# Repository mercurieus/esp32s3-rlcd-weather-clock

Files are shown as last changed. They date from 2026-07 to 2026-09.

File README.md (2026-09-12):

# ESP32-S3 RLCD Weather Clock

A simple desk clock built around the [Waveshare ESP32-S3-RLCD-4.2](https://www.waveshare.com/esp32-s3-rlcd-4.2.htm) — a 4.2" reflective LCD (e-paper-like) development board.

The project was written from scratch in **VS Code with ESP-IDF**, with help from AI along the way. I really don't like working in the Arduino environment, so ESP-IDF + VS Code was the natural choice here.

Based on the original [v-cu/esp32s3-rlcd-weather-clock](https://github.com/v-cu/esp32s3-rlcd-weather-clock).

**Calendar + clock** — month grid, analogue dial, four-day forecast and a quote strip:

Simulated calendar screen

**Main clock face** — big digits with the date tucked between the colon's dots:

Simulated main screen

*Both are simulations, not photographs — generated by
`tools/render_screen_mockup.py`, which reads the layout constants straight out
of `components/ui/`. The real panel is 1-bit with no grey, so its strokes are
harder-edged and its diagonals dither; the type here is the viewer's, not the
embedded Saira and Montserrat. They are drawn from the source so they cannot
quietly fall out of date, which is what happened to the photo they replaced.*

## Features

- **A calendar screen**: Monday-first month grid with today boxed and adjacent-month days a size down, an analogue dial beside it, the four-day forecast underneath and a quote strip at the foot. Arrow buttons page through the months
- Time on a low-power reflective display, with the date tucked into the gap between the colon's two dots — the one hole the big digits leave
- Indoor temperature and humidity from the onboard SHTC3 sensor — being an onboard sensor it sits close to the electronics, so readings are approximate, not lab-grade
- Current outdoor conditions and a 4-day forecast over Wi-Fi (Open-Meteo)
- A link indicator that shows what the radio is actually doing: a tick when the last sync worked and the radio is resting, a warning when the data has gone stale, and an aerial only while a connection genuinely exists
- Battery gauge with voltage, and a charging bolt when it is on power
- RTC timekeeping (PCF85063) across resets and reboots

## Setup

Everything configurable lives in menuconfig, under **Weather Clock**:

```
idf.py menuconfig
```

| Submenu | What to set |
|---|---|
| Wi-Fi | SSID and password |
| Time | POSIX timezone string, NTP server, the two daily time-sync hours |
| Weather | Latitude and longitude, refresh interval, stale threshold |
| Battery | Low-battery warning and critical-shutdown thresholds |

Your answers are written to `sdkconfig`, which is **not tracked by git** — it
holds your Wi-Fi password and your location. `sdkconfig.defaults` is tracked and
carries only project-wide settings, so a fresh clone builds with empty
credentials and you set your own.

## Controls

| Button | Action |
|---|---|
| Left | Force an immediate weather update |
| Middle | Long press: power off · Short press: power back on |
| Right  | Not used |

## How it works

The clock spends most of its time in **light sleep** to save power, waking once a minute to refresh the time from the internal RTC. Twice a day, at **05:00** and **15:00**, it syncs the RTC against NTP. Weather runs on its own shorter cycle - **every 30 minutes** by default - and shares a Wi-Fi bring-up with the time sync whenever the two coincide. All four values are configurable.

While a USB host is attached the clock does not light-sleep at all: light sleep suspends the USB Serial/JTAG peripheral, which would make the serial port disappear. On battery it sleeps as normal.

## ⚠️ Battery life

This module is **not particularly battery-friendly**. With the screen on, it draws around **8 mA even in light sleep**, which works out to roughly **14 days** of runtime on a single charge. Keep that in mind if you're planning to run it purely on battery.

## Keeping time without a backup cell

The PCF85063 has a pin for a backup cell, and **this build has none fitted**.
That is worth knowing because it decides what the clock does when it comes back:

- After a **reset or a panic reboot**, main power never dropped, so the RTC kept
  running and the time is still good.
- After an **unplug**, the oscillator stopped. The chip then returns a perfectly
  well-formed *wrong* time, and the only thing that says so is bit 7 of the
  seconds register — the oscillator-stop flag.

So the firmware reads that flag rather than trusting the value. With no network
and no valid RTC time it shows `--:--` until a sync lands, instead of a
confident and wrong `00:00`. A missed sync is never fatal either: it keeps
running on whatever time it has and retries on the next weather slot.

Fit a backup cell and time survives an unplug too.

## The finished build

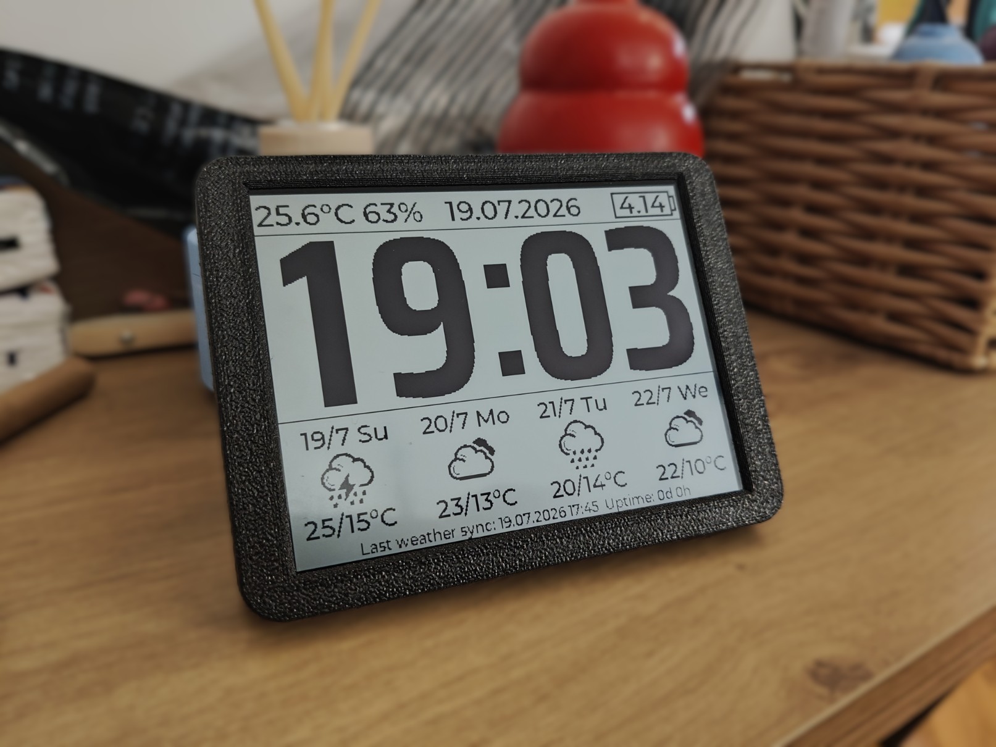
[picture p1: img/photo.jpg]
Finished clock


*The 3D-printed case. Note that this photo predates the current UI — the top bar
has since been rebuilt and the date moved onto the face.*

## Checking a layout without flashing

A 400px-wide 1-bit panel has no room to be wrong, and the way to get it wrong is
to try a layout with a flattering sample. `Fri 21` fitted the date column; `Wed
24` did not, and only one of those was ever typed in by hand.

```
python tools/verify_calendar_layout.py     # exits non-zero on an overflow
python tools/render_screen_mockup.py       # regenerate the mockup above
```

The checker measures against the **real** LVGL font tables — it parses the
`adv_w` values out of the generated font C files, including the sparse ranges
where `°` and the `LV_SYMBOL_*` glyphs live — and then tests the widest value
each field can hold rather than a typical one. Run it after touching anything in
`components/ui/`.

`TODO.md` carries the open leads, including a measurement that is suggestive but
not yet conclusive. `CHANGELOG.md` records what has changed and what is still
unverified.

## Hardware

- [Waveshare ESP32-S3-RLCD-4.2](https://www.waveshare.com/esp32-s3-rlcd-4.2.htm)

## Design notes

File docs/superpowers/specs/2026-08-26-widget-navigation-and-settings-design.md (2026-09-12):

# Widget navigation, Vista-style Cal+Clock, and on-device settings

Date: 2026-08-26
Status: approved for planning

## Context

The firmware currently has two screens (Main, Cal+Clock) toggled by a single
button, and no way to change anything without reflashing. This design adds
two-button navigation with focus and detail views, an on-device settings menu
backed by NVS, and redraws the Cal+Clock screen after the Windows Vista/7
taskbar clock flyout.

## Goals

- Two-button navigation: cycle screens, focus elements within a screen, open
  a detail view for the focused element.
- On-device settings for display preferences, timezone, sync schedule, plus
  read-only device info and a few actions.
- Cal+Clock redrawn as the Vista/7 flyout, with the second hand restored.
- Button hints as a transient overlay, not permanent screen furniture.

## Non-goals

- Wi-Fi AP + web configuration portal. Deferred; Wi-Fi credentials stay
  compile-time in `clock_config.h`.
- Text entry of any kind. Two buttons cannot do it usefully.
- Partial-panel refresh. `RLCD_Display()` hardcodes a full-screen window;
  changing that is a separate driver change, tracked as a follow-up.

## Hardware constraints

These shape every decision below and are easy to forget.

- **400 x 300, 1 bit.** `Lvgl_FlushCallback` in `main/main.cpp` thresholds
  RGB565 at `0x7fff`. There is no grey. Any stroke thinner than 2 px is
  anti-aliased into the threshold and breaks up.
- **Full-screen render on every refresh.** `LV_DISPLAY_RENDER_MODE_FULL` plus
  a 120000-iteration threshold loop plus a 15 KB SPI write plus a 50 ms
  `vTaskDelay`. Refresh only when something changed.
- **LVGL built-in allocator, 64 KB pool** (`CONFIG_LV_MEM_SIZE_KILOBYTES=64`).
  Object count matters. The Info page exposes free LVGL heap so this stays
  visible.
- **Light sleep between ticks.** The task wakes once a second or on a GPIO
  edge. Anything time-based must be driven from that tick; LVGL timers do not
  run on their own because `lv_timer_handler()` is only called from
  `Lvgl_Refresh()`.
- **Two usable GPIO buttons.** Select = `GPIO_NUM_18`, OK = `GPIO_NUM_0`.
  Confirmed, not assumed: the esp32s3-rlcd-smart-clock project on this same
  board does `ButtonInput s_buttons(GPIO_NUM_18, GPIO_NUM_0)`. The third case
  cutout is the PMU power button and is not software-readable.
- **ES8311 output codec on the shared I2C bus**, I2S on MCLK `GPIO_NUM_16`,
  BCLK `GPIO_NUM_9`, WS `GPIO_NUM_45`, DOUT `GPIO_NUM_8`, speaker PA enable
  `GPIO_NUM_46`. The speaker itself plugs into a header and may not be fitted.

## Architecture

New components, each with one job:

| Unit | Responsibility | Depends on |
|---|---|---|
| `components/input/buttons.[ch]` | Debounce, classify short/long press, expose events | driver/gpio, esp_sleep |
| `components/ui/nav.[ch]` | Navigation state machine. Pure C, no LVGL, no ESP-IDF | nothing |
| `components/ui/overlay.[ch]` | Top bar + hint overlay + focus frame on `lv_layer_top()` | lvgl |
| `components/settings/settings.[ch]` | Typed settings struct, NVS load/save, TZ table | nvs_flash |
| `components/ui/screen_settings.[ch]` | Settings list rendering and row actions | lvgl, settings |

`nav.c` having no dependencies is deliberate: it is the piece most likely to
harbour bugs and the only piece that can be tested away from hardware.

## Input layer

`user_config.h` gains:

```c
#define BTN_OK_PIN      GPIO_NUM_0    /* BOOT, confirmed working */
#define BTN_SELECT_PIN  GPIO_NUM_18   /* KEY - confirmed against sibling board */
```

Both configured input, pull-up, active low, with
`gpio_wakeup_enable(pin, GPIO_INTR_LOW_LEVEL)`.

On wake with cause `ESP_SLEEP_WAKEUP_GPIO`, poll both pins; whichever reads
low is the pressed one. Debounce 20 ms, then poll at 20 ms until release or
`BTN_LONG_MS` (600). A press held past 600 ms emits its LONG event
immediately, then waits for release without emitting again.

Emits exactly one of: `BTN_EV_SELECT_SHORT`, `BTN_EV_SELECT_LONG`,
`BTN_EV_OK_SHORT`, `BTN_EV_OK_LONG`.

This replaces the inline busy-wait currently in `clock_task`.

## Navigation state machine

```c
typedef enum { NAV_SCREEN, NAV_FOCUS, NAV_DETAIL, NAV_SETTINGS } nav_mode_t;
```

| Mode | Select short | Select long | OK short | OK long |
|---|---|---|---|---|
| `SCREEN` | next screen | — | enter `FOCUS` (index 0) | `SETTINGS` |
| `FOCUS` | next element (wraps) | back to `SCREEN` | open `DETAIL` | `SETTINGS` |
| `DETAIL` | — | back to `FOCUS` | back to `FOCUS` | `SETTINGS` |
| `SETTINGS` | next row (wraps) | exit to `SCREEN` | cycle value / run action | — |

Screen cycle: **Main -> Cal+Clock -> Main**. Settings is modal and not in the
cycle. Detail is a transient overlay, not a screen.

Focusable elements:

- **Main**: `[indoor sensor] [day1] [day2] [day3] [day4]` — 5 elements.
- **Cal+Clock**: the days of the displayed month, 1..N. Advancing past N
  browses to the next month at day 1; retreating before 1 browses to the
  previous month at its last day. This is what makes the `< >` month arrows
  meaningful.

`nav_handle(nav_state_t *, btn_event_t)` returns a `nav_action_t` describing
what the caller must redraw. The state machine itself touches no widgets.

## Shared overlay on `lv_layer_top()`

`lv_layer_top()` floats above whichever screen is loaded and survives
`lv_screen_load()`. Moving the top bar there **removes the duplication added
in ccffbf5**: `calendar_update_top_bar()` and the calendar's second widget set
are deleted, and one set of temp/humidity/date/battery widgets serves every
screen.

The focus frame also lives here, positioned in absolute screen coordinates, so
one frame object can outline an element on any screen — including the top bar
itself, which is how Main's `[indoor sensor]` element gets highlighted.

Screens shrink to y 38..300. Main barely moves: it already had a rule at y=34,
so deleting its own top-bar widgets leaves the rest in place.

### Hint overlay

A hidden box on `lv_layer_top()`, roughly 320x40 centred near the bottom,
showing the current mode's button labels:

```
   Select: next day        OK: details        hold OK: menu
```

Shown for 5 s at boot and 2.5 s after any button event. **Auto-hide is driven
from the one-second task tick, not an LVGL timer** — `lv_timer_handler()` only
runs inside `Lvgl_Refresh()`, so a timer would never fire while idle. The task
holds `hint_until_ms` and hides the overlay on the first tick past it.

Cost: one extra refresh roughly 2.5 s after each button press.

## Cal+Clock screen

```
+--------------------------------------------------+  y
|  25.6C 63%   19.07.2026              [4.14]      |  0..36   shared top bar
|==================================================|  34..36  rule
|            Wednesday, 26 August 2026             |  38..56  montserrat_16
|   <  August 2026  >            .-''''''-.        |  58..74  montserrat_14
|   Mo Tu We Th Fr Sa Su       .'    |     '.      |
|   28 29 30 31  1  2  3      /      |       \     |  76..216 grid, 7 x 20
|    4  5  6  7  8  9 10     |       o----    |    |  62..212 dial, 150 sq
|   11 12 13 14 15 16 17     |      /         |    |
|   18 19 20 21 22 23 24      \    /         /     |
|   25[26]27 28 29 30 31       '.          .'      |
|    1  2  3  4  5  6  7         '-......-'        |
|                                  19:03:42        |  214..232 montserrat_16
|--------------------------------------------------|  236     rule
| (~)Su  (/)Mo  (~)Tu  (~)We                       |  240..276 weather row
| 25/15  23/13  20/14  22/10                       |
|--------------------------------------------------|
| Sunrise 05:52  Sunset 20:31  Day 14h39m  Moon 68%|  280..295 montserrat_12
+--------------------------------------------------+
```

Geometry constants (all derived, none eyeballed):

- Grid columns keep the current scheme: 7 fixed-width centred labels, header
  as line 0, `CAL_COL_X0 = 6`, `CAL_COL_W = 30`, `CAL_ROW_H = 20`, pitch from
  `text_line_space`, not `pad_row`.
- Dial `x 238..388`, `y 62..212`.
- Today box and focus frame both derive from the column constants, so they
  cannot drift off a cell.

### Leading and trailing days

Vista greys them. There is no grey on this panel. They render in
**montserrat_12 against the month's montserrat_14**, which reads as
subordinate without needing a second colour.

### Dial

- 12 major ticks, 3 px wide, 10 px long.
- 48 minor ticks, 2 px wide, 4 px long. At r=68 adjacent ticks are ~7 px
  apart, so 2 px survives the threshold. 1 px does not — that is what made the
  old minor ticks noise.
- Hour hand 5 px / 34 long, minute 3 px / 52, **second 2 px / 58**, all pure
  black. The old `0x888888` second hand thresholded to white, which is why it
  was invisible.
- 9x9 square hub.

### Day detail overlay

OK on a focused day opens: weekday, ISO week number, day of year, days from
today, and — if the day falls inside the 4-day forecast — its icon, high/low,
rain probability and wind.

### Sun and moon

Sunrise, sunset and day length come from Open-Meteo. Moon phase is computed
locally, no network:

```
phase = frac((jd - 2451550.1) / 29.530588853)     /* ref new moon 2000-01-06 */
illum = (1 - cos(2*pi*phase)) / 2
```

Named across eight buckets (new, waxing crescent, first quarter, waxing
gibbous, full, waning gibbous, last quarter, waning crescent).

## Weather API extension

The existing single request gains three daily fields at no extra network cost:

```
&daily=weathercode,temperature_2m_max,temperature_2m_min,
       sunrise,sunset,precipitation_probability_max,wind_speed_10m_max
```

`WeatherDay` gains `sunrise_min`, `sunset_min` (minutes past local midnight),
`precip_prob`, `wind_max`. `timezone=auto` is already set, so the returned sun
times are local.

## Settings

One scrolling list on its own screen. Select moves the row, OK cycles the
value or runs the action, long Select exits.

**Display** — time 24h/12h · date format Weekday (`Fri 26 Aug`, default) /
`DD.MM.YYYY` / `YYYY-MM-DD` / `MM/DD/YYYY` · °C/°F · show seconds on/off ·
week starts Monday/Sunday

The Weekday format is `EEE D MMM` in CLDR terms — abbreviated weekday, day,
abbreviated month, no year — the pattern calendar apps use for a day header.
It ships as the default because it is what the shared overlay's top bar
actually shows (see the Cal+Clock mockup); the year is not lost, since the
opened calendar's own heading carries it. `WEEKDAY_NAMES` already exists in
`clock_task.c` for the forecast row; the top bar needs its 3-letter form,
plus a 3-letter month table that does not yet exist anywhere in the
firmware.

**Time** — timezone from a preset POSIX-TZ table · sync hour 1 (0..23) ·
sync hour 2 (0..23)

**Actions** — sync weather now · sync time now · reboot

**Info** (read-only) — firmware version · uptime · battery mV and % · free
LVGL heap, internal heap, PSRAM · SSID and RSSI · last NTP sync · RTC state

### NVS schema

```c
#define SETTINGS_VERSION 1

typedef struct {
    uint8_t version;
    uint8_t time_24h;         /* 0/1                                    */
    uint8_t date_fmt;         /* 0 Weekday, 1 DD.MM.YYYY, 2 YYYY-MM-DD, 3 MM/DD/YY */
    uint8_t temp_f;           /* 0/1                                    */
    uint8_t show_seconds;     /* 0/1                                    */
    uint8_t week_start_sun;   /* 0/1                                    */
    uint8_t tz_index;         /* index into TZ_TABLE                    */
    uint8_t sync_hour_1;      /* 0..23                                  */
    uint8_t sync_hour_2;      /* 0..23                                  */
    uint8_t reserved[7];      /* room to grow without a version bump    */
} settings_t;
```

Namespace `clock`, key `settings`, stored as a blob. Missing or mismatched
version loads defaults and writes them back. Defaults: 24h, **Weekday date
format**, °C, seconds on, Monday, EET, 05:00 / 15:00. This is the one default
that changes device behaviour rather than preserving it — a deliberate choice,
since the redesigned overlay is built around the shorter format and reverting
to `DD.MM.YYYY` is one Settings press away.

The TZ table holds roughly sixteen labelled POSIX strings (UTC, London,
Berlin, Kyiv, Moscow, Dubai, India, Bangkok, China, Japan, Sydney, New York,
Chicago, Denver, Los Angeles). Default is the current
`EET-2EEST,M3.5.0/3,M10.5.0/4`.

## Chimes

An old-clock chime, synthesised rather than sampled. Nothing is stored in
flash: a struck bell is a handful of inharmonic partials with exponential
decay, which is roughly twenty lines of arithmetic.

### Timbre

Each strike sums five partials at the classic bell ratios against the
strike note, with higher partials decaying faster:

| Partial | Ratio | Relative gain | Decay |
|---|---|---|---|
| hum | 0.5 | 0.30 | slowest |
| fundamental (prime) | 1.0 | 1.00 | slow |
| tierce | 1.2 | 0.50 | medium |
| quint | 1.5 | 0.25 | fast |
| nominal | 2.0 | 0.60 | fast |

Output at 16 kHz mono, matching the sibling project's codec configuration.
That is ample: the highest partial of the highest bell is under 900 Hz.

### What plays

Westminster quarters, in E major, on the four bells
E4 329.63, F#4 369.99, G#4 415.30, B3 246.94:

| Time | Phrase |
|---|---|
| :15 | G# F# E B |
| :30 | E G# F# B, B F# G# E |
| :45 | E G# F# B, B F# G# E, G# E F# B |
| :00 | G# F# E B, B E F# G#, B F# G# E, G# E F# B, then the hour strike |

**The hour strike is what makes each hour sound different**: a deeper bell
(E3, 164.81 Hz) struck once at one o'clock through twelve times at twelve,
roughly two seconds apart. This is what a grandfather clock does, and it is
the classic way an hour is audibly identifiable without looking.

Twelve o'clock therefore runs about 45 seconds. Playback lives on its own
low-priority `chime_task` fed by a queue, so the one-second display tick and
the second hand keep running throughout. Audio is generated in chunks and
streamed to `esp_codec_dev_write`; a full phrase is never buffered whole.

The PA on `GPIO_NUM_46` is enabled only for the duration of a phrase.

### Settings rows

- **Chimes** — Off / Hour strike only / Westminster + strike. Default **Off**,
  because a speaker may not be fitted and an unexpected 45-second chime is a
  poor first-boot experience.
- **Quarter chimes** — Off / On. Only meaningful with Westminster selected.
- **Quiet hours** — Off / 22:00-08:00 / 23:00-07:00 / custom start and end.
  Default 22:00-08:00. Nothing chimes inside the window.
- **Volume** — 0 to 100 in steps of 10, applied through the codec.
- **Test chime** — an action row that plays a single strike, so the speaker
  can be verified without waiting for an hour boundary.

`settings_t` gains `chime_mode`, `chime_quarters`, `quiet_start`, `quiet_end`
and `volume`, taken from the existing `reserved[7]` bytes, so the NVS version
byte does not need to change.

### Scheduling

The existing one-second tick already knows the minute boundary. The chime
scheduler fires when the minute changes to 00, 15, 30 or 45, is enabled for
that quarter, and falls outside quiet hours. It queues a request and returns
immediately.

A missed boundary is never made up: if the device was asleep, resyncing or
mid-chime, the request is dropped rather than played late.

## RTC stores UTC

`wifi_sync.c:60-61` sets `TZ` then calls `localtime_r`, so `Pcf85063_SetTime()`
writes **local** time to the RTC.

Two consequences: a runtime timezone setting would not take effect until the
next NTP sync, up to 12 hours later; and — independent of this work — **at a
DST boundary the clock stays an hour wrong until 05:00 or 15:00.**

Change: the RTC stores UTC. `Pcf85063_GetTime()` yields UTC, which is
converted to a `time_t` and passed through `localtime_r()` for display, with
`TZ` set from `settings.tz_index` at boot and whenever the setting changes.

Migration: devices flashed with this build have a local-time RTC until their
first NTP sync, after which they are correct. Worst case is one wrong-by-offset
period on first boot after update; acceptable and self-healing.

This lands as its own commit, before any navigation work, so timekeeping can
be verified in isolation.

## Refresh and power

| State | Refresh rate |
|---|---|
| Main active | 1/s (colon blink, unchanged) |
| Cal+Clock active | 1/s (second hand) |
| Settings active | on input only |
| Detail overlay | on input only |
| Any state | one extra refresh when a hint expires |

The second hand costs exactly what Main's colon blink already costs, so it is
not a regression — but it only ticks while Cal+Clock is the active screen.

## Testing

No host C compiler is available on this machine (only the Espressif
cross-toolchain), so:

- **Nav state machine** — `nav.c` stays dependency-free so it can be host
  tested later. For now, the transition table is mirrored in a Python model
  and checked exhaustively over every (mode, event, screen, focus index)
  combination against invariants: mode always valid, focus index always in
  range, every mode reachable, every mode can return to `SCREEN`, Settings
  always reachable and always exitable.
- **Layout geometry** — asserted against real font metrics parsed from the
  LVGL font tables, not eyeballed. This is the method that caught the column
  alignment and quote-wrapping problems in ccffbf5.
- **Calendar month browsing** — extends the existing 12-year harness to cover
  crossing month and year boundaries in both directions.
- **Moon phase** — checked against known new and full moon dates.
- **Settings persistence** — round-tripped on device via the Info page across
  a reboot.

## Milestones

Each builds, flashes, and is verifiable on its own.

1. RTC to UTC, timezone applied for display only.
2. Input layer + nav state machine + hint overlay. Select cycles Main and
   Cal+Clock; long OK opens a stub Settings screen. Also logs GPIO transitions
   so the Select pin can be confirmed.
3. Overlay onto `lv_layer_top()`; delete the duplicated top bars.
4. Cal+Clock Vista redraw: dial with second hand, month browsing, day detail.
5. Weather API extension and the sun/moon strip.
6. Settings screen and NVS.
7. Chimes: codec bring-up, bell synthesis, schedule, chime settings rows.

## Risks

- **A speaker may not be fitted.** The board only provides a header. Chimes
  default to off, the ES8311 is probed over I2C at boot, and if it does not
  answer the chime rows render as "no audio hardware" rather than failing.
- **Chime playback is long.** Westminster on the hour plus twelve strikes runs
  around 45 s. It must not block the display tick, hence the dedicated task.
- **LVGL 64 KB heap.** Settings rows, the hint overlay and the detail view all
  add objects. The Info page reports free LVGL heap so pressure is visible;
  if it becomes tight, the Settings list is the natural candidate for building
  rows on demand rather than up front.
- **`lv_layer_top()` persistence across `lv_screen_load()`** is assumed and
  must be confirmed early in milestone 3, since the whole overlay design rests
  on it.
- **Hint overlay refresh cost** adds one full-panel write per button press.
  Measurable, but worth watching on battery.

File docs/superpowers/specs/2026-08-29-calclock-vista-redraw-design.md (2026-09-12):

# Cal+Clock Vista redraw and accurate SPI transfer wait

Date: 2026-08-29
Status: approved for planning

## Context

This is milestone 4 of
`docs/superpowers/specs/2026-08-26-widget-navigation-and-settings-design.md`,
written out and refined into its own spec the same way milestones 1-3 became
`docs/superpowers/plans/2026-08-26-navigation-foundation.md`. It formalizes
the visual decisions made in a mockup session and captured in
`TEMP-visual-design-notes.md` (delete that file once this spec is committed —
its content is folded in below, with one section explicitly superseded, see
"Nav model" below), resolves the one question that session left open, and
adds a small, unrelated fix to the SPI transfer path found worth doing at the
same time since milestone 4 is what makes it matter (a live second hand,
ticking every second, is the first thing on this device that benefits from
not padding every refresh with a guessed delay).

Two things surfaced during brainstorming are explicitly **out of scope** here
and noted for their own future spec:

- **Windowed/partial SPI refresh.** Still deferred, as in the parent spec's
  non-goals. The transfer-wait fix below is an orthogonal, lower-risk
  improvement chosen instead — it does not reduce bytes transferred, only
  removes a padded guess, and touches none of the panel's undocumented
  column/row addressing.
- **A "weather station" screen** (live current conditions, hourly forecast,
  an analog clock, styled after a classic weather station instrument). A real
  idea, but it is a new top-level screen with its own API surface
  (`hourly=...`, `current_weather=true` — both beyond what milestone 5
  already plans) and its own visual language. Noted on the roadmap; not
  designed here.

## Goals

- Redraw the existing Cal+Clock screen after the Windows Vista/7 taskbar
  clock flyout: plain analog dial with a working second hand, month
  calendar grid, metal-styled header/bezel/buttons via dithering.
- Working month browsing via the `<`/`>` arrows, replacing the parent
  spec's per-day focus (see "Month browsing" below for why).
- Replace the SPI flush path's blind `vTaskDelay(50)` with an accurate wait
  on the transfer's actual completion.

## Non-goals

- Anything in the "out of scope" list above.
- Any change to `nav.c` (see "Nav model" below).
- Double-buffering `DispBuffer` for a truly non-blocking transfer. Considered
  during brainstorming and rejected for now as more complexity than this
  milestone's payoff justifies — see "SPI transfer wait" below. Left as a
  future option if the accurate-wait version ever proves insufficient.

## Nav model (resolved)

Main and Cal+Clock remain two equal, symmetric top-level screens, cycled by a
short Select press, exactly as implemented in the navigation-foundation plan.
**No `nav.c` change.**

This explicitly supersedes `TEMP-visual-design-notes.md`'s "Calendar
drill-down, not buttons-on-a-tile" section in full: the idea of Main gaining
a sixth focus tile that opens Cal+Clock as a Detail overlay is rejected.
There is no overview/opened distinction — Cal+Clock is drawn the same way
however you arrive at it. The round `< >` month buttons described there as
living "only in the opened view" simply don't apply to that framing; see
"Dial and grid" below for where month browsing actually lives.

## SPI transfer wait

**Current state.** `Lvgl_FlushCallback` (`main/main.cpp:17`) writes the
dirty pixels into `DispBuffer` via `RLCD_SetPixel`, calls
`RlcdPort.RLCD_Display()`, which sends the whole buffer through
`esp_lcd_panel_io_tx_color()` — itself asynchronous, queuing onto SPI/DMA and
returning quickly — then immediately calls `lv_disp_flush_ready()`.
`Lvgl_Refresh()` (`components/app_bsp/lvgl_bsp.cpp:37`) then unconditionally
sleeps 50 ms before returning to the caller, on every single refresh. That
delay is not just a wasted guess: `DispBuffer` is a single, persistent
full-frame buffer (`components/port_bsp/display_bsp.cpp`), not
double-buffered, so the delay is what currently prevents the next refresh's
`RLCD_SetPixel` calls from mutating a buffer whose previous contents are
still being DMA'd out — a real, if accidental, safety mechanism.

**Change.** Register `on_color_trans_done` via
`esp_lcd_panel_io_register_event_callbacks()` (not a field on the SPI IO
config — it's registered separately, see `esp_lcd_types.h`), backed by a
binary FreeRTOS semaphore signalled from that callback.

**Where the wait actually has to go is the subtle part.** Waiting at the top
of `RLCD_Display()` — the first design considered here — is too late: by the
time `RLCD_Display()` is called, `Lvgl_FlushCallback` has *already* written
this frame's pixels into `DispBuffer` via `RLCD_SetPixel`, so a still-in-
flight previous transfer could already have raced against those writes
before anyone waited for anything. The wait must happen **before the pixel
writes**, not before the send. Concretely:

- `DisplayPort` gains a `SemaphoreHandle_t xfer_done_` member: a **binary**
  semaphore (only "is a transfer outstanding" matters, never a count),
  created in the constructor and given once immediately so the first call
  doesn't block forever waiting for a transfer that never started.
- A new public method, `void RLCD_WaitTransferDone()`, blocks on it.
- The registered callback gives the semaphore from ISR context
  (`xSemaphoreGiveFromISR`).
- `Lvgl_FlushCallback` (`main/main.cpp:17`) calls `RlcdPort.RLCD_WaitTransferDone()`
  as its **first statement**, before its `RLCD_SetPixel` loop — this is what
  actually closes the race, for both the ordinary case and `PARTIAL` render
  mode's multiple flush calls per refresh (each flush's writes wait for
  whatever the *previous* flush's `RLCD_Display()` kicked off, whether that
  was in this refresh cycle or the last one).
- `RLCD_Display()` itself is otherwise unchanged — it sends immediately,
  trusting the caller already waited before writing.
- `Lvgl_Refresh()` drops its `vTaskDelay(50)` entirely.

This still blocks the caller — `DispBuffer` being single-buffered means it
must — but for the transfer's actual duration (≈24 ms at the current 10 MHz
SPI clock for the full 30000-byte buffer) rather than a padded 50 ms guess,
and it is now a guarantee instead of a hope. True non-blocking would need
double-buffering `DispBuffer` and tracking render-pass boundaries across
possibly multiple `PARTIAL`-mode flush calls per refresh — rejected above as
more complexity than this milestone's payoff justifies.

**Cross-checked against the sibling `esp32s3-rlcd-smart-clock` project**,
which shares this exact driver (`DisplayPort`, same `RLCD_Display()`, same
`esp_lcd_panel_io_tx_color`, same 10 MHz `pclk_hz`) with no LVGL involved —
its own animation loop (`main/display_animations.cpp:74`) calls
`RLCD_Display()` and waits only 5 ms, not 50, for the same 30000-byte
buffer. Neither project has a completion callback; that 5 ms is as much a
guess as our 50 ms, just a tighter one, and is exposed to the same
single-buffer race in principle even if it hasn't produced visible
artifacts there in practice. It's useful evidence that the true transfer
time is well under 50 ms, but it is not a pattern worth copying — it
confirms the direction (replace the guess with a real wait), not a number
to borrow.

**Testing.** Build and flash; confirm on hardware that the Main and
Cal+Clock screens still render correctly and nothing regresses (this is a
timing-only change, so "looks identical, feels identical or snappier" is the
bar — no new automated test is meaningful here).

## Dial and grid

**Dial:** plain Vista style — ticks only, no numerals, no chapter ring, no
outlined hand polygons (the engraved/skeuomorphic treatment explored earlier
was rejected and must not be resurrected). Geometry:

| Element | Spec |
|---|---|
| Dial position | x 238..388, y 62..212 |
| Major ticks | 12, 3 px wide, 10 px long |
| Minor ticks | 60 (not 12 — see below), 2 px wide, 4 px long |
| Hour hand | 5 px wide, 34 px long |
| Minute hand | 3 px wide, 52 px long |
| Second hand | 2 px wide, 58 px long |
| Hub | 9x9 px square |
| Colour | all pure black — no `0x888888` on this panel; that grey is what made the parent spec's original second hand thresholded invisible |

Minor ticks are 60, not the 12 the parent spec originally specified: at
r=58 adjacent 60-tick spacing is ~6.3 px, wide enough for a 2 px tick to
survive the 1-bit threshold; a 1 px tick does not, which is what produced
speckle noise when this was first tried.

**Grid:** unchanged from the parent spec — 7 fixed-width centred columns,
header as line 0, `CAL_COL_X0 = 6`, `CAL_COL_W = 30`, `CAL_ROW_H = 20`, pitch
from `text_line_space` (not `pad_row`). Leading/trailing days render in
montserrat_12 against the current month's montserrat_14, reading as
subordinate without needing a second colour this panel doesn't have.

**Month browsing:** as the parent spec already specifies — advancing focus
past the last day of the displayed month browses into the next month at day
1 (and symmetrically backward). The `< >` glyphs next to the month/year
header are a static visual affordance for this, not separate focusable
elements — no additional nav.c or focus-count change.

## Metal via dithering

Two techniques, both native to 1-bit displays, applied to structure only —
**never the dial face**, which stays the plain style specified in "Dial and
grid" above:

- **Ordered dithering** (Bayer 4x4 matrix): a real per-pixel grey gradient,
  thresholded through the matrix *before* LVGL sees it — a plain grey fill
  collapses to solid under the panel's hard threshold, so the gradient must
  already be dithered pixels by the time it's drawn.
- **Bevel pairs** for relief: a light edge on one side, dark on the other,
  two 1 px lines per edge.
- **Hard rule:** never dither behind text — it destroys glyphs at this
  panel's pitch. Anything carrying type sits on plain white.

Applied to: the header rail (dithered band, dark lower lip, bright ridge
about a third of the way down, dark lower lip again — a "rolled rail" rather
than a flat bar), the dial's bezel, and the month `< >` buttons (shaded via
hemisphere-normal-against-light-vector, not a flat gradient fill). The
shared top bar's four readings (temp, humidity, date, battery) sink into the
rail as recessed white plaques — dark edge top-left, light edge
bottom-right — which is what keeps their text off the dither per the hard
rule above.

**The header rail is `components/ui/overlay.c`'s shared top bar** — on
`lv_layer_top()`, so this reaches Main too, not just Cal+Clock. Confirmed
with the user: one visual language for both screens, not a Cal+Clock-only
treatment. The dial bezel and month buttons remain Cal+Clock-only, in
`screens.c`.

**Hardware verification required before committing to this.** The mockup's
dither assumes the panel renders isolated single pixels cleanly; if adjacent
dithered pixels bleed together the checker pattern collapses to flat grey
and the whole technique needs rethinking. This is the first implementation
step (see "Implementation notes" below) — flash a standalone test pattern
(the tone-ramp swatches from the mockup) and confirm on the actual screen
before writing any of the bezel/rail code for real.

Exact pixel geometry for the metal treatment (dither matrix tiling, bevel
positions, rail band y-ranges) was worked out live in the mockup as
JavaScript, not yet transcribed into tables here — the implementation plan
must derive and record these the same way the rest of this document does,
not eyeball them from the mockup.

## Month browsing (revises the parent spec)

The parent spec gave Cal+Clock per-day focus (1..N days) with wrap-forward
into the next month and wrap-backward into the previous, plus a day-detail
overlay (weekday, ISO week, day of year, days from today, weather). Dropped
during brainstorming: per-day focus isn't needed, only month browsing is —
and `nav.c` has no backward-navigation event at all (`SELECT_SHORT` only
ever moves focus forward, wrapping), so per-day "retreat before day 1" was
never actually reachable through the two-button vocabulary as originally
worded. **This whole day-focus and day-detail design is replaced** by:

Cal+Clock gains exactly two focusables: the `<` and `>` month arrows
(`nav_focus_count(NAV_SCREEN_CALCLOCK) = 2`, index 0 = previous, index 1 =
next — up from 0 today). Select cycles focus between them, exactly as
`nav.c` already does for Main's five. OK on a focused arrow shifts the
*displayed* month in that direction and redraws the grid.

`nav.c` still has no notion of "perform an action, don't open a view" — OK
on a focused element unconditionally enters `NAV_DETAIL`. Cal+Clock uses the
same escape hatch `NAV_SETTINGS` already relies on ("caller acts on the row,
then redraws"): `clock_task.c` recognizes `mode == NAV_DETAIL && screen ==
NAV_SCREEN_CALCLOCK`, performs the month shift, and immediately sets
`s_nav.mode` back to `NAV_FOCUS` in the same handler — the user never sees a
detail view, an OK press on `<`/`>` just feels like it directly changes the
month, and repeated presses browse further. No `nav.c` change.

**Displayed vs. real "today."** A new pair of statics,
`s_cal_disp_year`/`s_cal_disp_month`, tracks which month is on screen,
independent of the RTC's real date. It resets to the real current month
every time Cal+Clock is loaded (leaving it, then coming back later, always
starts back at the current month rather than wherever browsing left off —
predictable over clever). The "today" highlight is shown only when the
displayed month equals the real current month; otherwise it's hidden. A
real-world midnight rollover while the display is on a browsed-away month
does not snap the view back — only the highlight's visibility, computed
fresh each redraw, reacts to it.

There is no day-detail overlay in this milestone. If per-day detail is
wanted later, it needs its own design — including how to reach a specific
day without a backward nav event — not assumed here.

## Roadmap note

Added to the backlog, not designed here: a new top-level screen showing live
current outdoor conditions, an hourly forecast, and an analog clock styled
after a classic weather station instrument. Needs its own brainstorm
(new API surface, new screen in `nav.c`, new visual language) when its turn
comes.

## Implementation notes

Suggested step order for the implementation plan:

1. **SPI transfer wait fix** — self-contained, no visual dependency, lowest
   risk. Verify on hardware that nothing regressed.
2. **Dither hardware verification** — flash the tone-ramp test pattern,
   confirm pixels don't bleed, *before* writing any bezel/rail code.
3. **Dial and second hand** — geometry above, verify on hardware (the second
   hand not going invisible, in particular, is the whole point of this
   milestone per the parent spec).
4. **Grid, month browsing (plain `<`/`>` hit-boxes, no styling yet),
   leading/trailing day styling.**
5. **Header rail, bezel, and the `<`/`>` buttons' final dithered/bevelled
   look** — only once step 2 has confirmed the technique holds up; the
   arrows' focus/action logic from step 4 is untouched, only their paint.
6. **Geometry test coverage** — assert against real font metrics as the
   parent spec's testing section describes, not eyeballed.

## Testing

- Layout geometry asserted against real font metrics parsed from LVGL's
  font tables (the method that caught the column alignment and
  quote-wrapping problems in `ccffbf5`), not eyeballed.
- Dial tick/hand geometry checked for 1-bit-threshold survival the same way
  the minor-tick width was derived above (spacing at radius vs. stroke
  width), not just visually.
- SPI transfer wait: hardware smoke test only, as noted above — no
  meaningful automated test for a timing-only change.
- Dither hardware verification: the tone-ramp test pattern step above is
  itself the test; its result (bleed or no bleed) gates whether step 5 in
  "Implementation notes" proceeds as designed or needs rethinking.

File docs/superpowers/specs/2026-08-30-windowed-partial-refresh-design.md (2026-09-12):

# Windowed Partial Refresh Design

> **Correction (2026-08-30, after this spec's implementation was hardware-tested
> and reverted):** the root-cause conclusion below - "the roll is the ST7305
> panel's own liquid-crystal optical settling time, a physical property" - is
> wrong. A direct hardware A/B test against the commit right before Task 1's
> `RLCD_WaitTransferDone()` fix (`ff95e25`) showed that build had NO visible
> roll. That commit *also* removed a blind `vTaskDelay(pdMS_TO_TICKS(50))`
> that used to run after every LVGL refresh pass, believing it to be a
> redundant, unproven race-condition workaround superseded by the new
> semaphore wait. It was redundant for the DMA race (the semaphore genuinely
> fixes that), but it was independently also giving the ST7305 panel time to
> finish its own internal settle cycle after a send - something
> `on_color_trans_done` firing on SPI-wire completion doesn't guarantee.
> Restoring that delay (`firmware/components/app_bsp/lvgl_bsp.cpp`,
> `Lvgl_Refresh()`, commit `04e0c4e`) eliminated the roll entirely, full-panel
> sends included. The windowed partial-refresh design and implementation
> below never had a chance of fixing the actual cause, which is why every
> policy variant tried on hardware (always-window, threshold-gated,
> clock-digit-allow-list) showed no reliable improvement - see
> `firmware/main/main.cpp`'s git history for that build-and-revert sequence.
> Independently corroborated: Waveshare's own reference examples for this
> exact board (`ESP32-S3-RLCD-4.2/02_Example/ESP-IDF/{08_LVGL_V8_Test,
> 09_LVGL_V9_Test}`, this project's likely ancestor) hardcode the identical
> 50ms as `LVGL_TASK_MIN_DELAY_MS`, the floor on their own background LVGL
> task's polling interval - the same requirement enforced by a standing
> task's pacing instead of an explicit delay. This project has no
> equivalent task (`ClockTask` calls `esp_light_sleep_start()` to sleep the
> CPU between updates, incompatible with a free-running ~50ms-cadence
> task), so `Lvgl_Refresh()` pays this cost explicitly - see
> `RLCD_PANEL_SETTLE_DELAY_MS` in `lvgl_bsp.h`.
> The rest of this document is kept as a historical record of the addressing
> reverse-engineering (CASET/RASET math, `DispBuffer` packing) and of a
> plausible-seeming but ultimately incorrect root-cause chain - useful if
> windowing is ever revisited for a genuine reason (e.g. SPI bus contention
> with another peripheral), but not as an explanation of the roll.
>
> **Follow-up (same day):** with the settling delay restored, the
> implementation below got one clean re-test - windowing on top of correct
> timing, the comparison this document was actually meant to make. Still no
> benefit: the hint overlay's window and a full-panel screen switch settled
> at about the same visible speed. So the addressing/extraction work here
> is real and correct, but the premise it served - that a smaller window
> settles faster - doesn't hold on this panel. The settle cost looks fixed
> per send, not proportional to window area. Reverted again
> (commit `3b16fc2`), this time on solid evidence rather than a confounded
> test.

## Context

`DisplayPort::RLCD_Display()` (`firmware/components/port_bsp/display_bsp.cpp`) always
ships the entire 15000-byte packed panel buffer over SPI, addressed to the panel's
full fixed column/row window, regardless of how small the actual dirty rect was.
This was a known, documented limitation (see the comment above `RLCD_Display()`)
carried since before this session.

During execution of the Cal+Clock Vista redraw plan
(`docs/superpowers/plans/2026-08-29-calclock-vista-redraw.md`), Task 1 fixed a real
DMA race by adding an accurate SPI transfer-done wait
(`DisplayPort::RLCD_WaitTransferDone()`), then a follow-up fix batched multiple
LVGL dirty-rect flushes into a single send per refresh pass. Both fixes are
hardware-verified and committed. Neither one caused the following symptom, but
removing the DMA race made it visible where it had previously been masked by
undefined racy behavior:

Large-area screen updates (switching between Main and Cal+Clock, the hint overlay
showing/hiding) show a slow, visible top-to-bottom "roll" - roughly 50px/second,
so a full 300px-tall change takes around 6 seconds to visually settle. A tiny
change (the once-a-second colon blink) shows no such roll, even though it goes
through the exact same full-panel SPI send.

Two hypotheses were tested and hardware-refuted before this design:

- **SPI transfer speed.** Ruled out by the numbers alone: `DisplayLen` is 15000
  bytes at a 10MHz SPI clock, ≈12ms to transmit - three orders of magnitude too
  fast to be the visible cause.
- **FRCTRL (0xB2) frame-rate register.** The panel's `RLCD_Init()` ends by
  switching to LPM (Low Power Mode, ~1Hz) instead of staying in HPM (High Power
  Mode, ~25.5Hz) - a plausible cause, since 1Hz means roughly a second per frame.
  Hardware-tested and refuted: switching to HPM produced no measurable change
  (~50px/sec roll in both modes). Reverted (commit `e65354b`) - HPM has a real
  battery cost with zero visible benefit.

Current best understanding: the roll is the ST7305 panel's own liquid-crystal
optical settling time (a physical property of "ultra-low-power a-Si TFT" reflective
panels, per the datasheet's own framing) - not an SPI clock-rate or addressing-window
limit on its own. It behaves like a raster-style settling scan whose visible
duration scales with how much of the panel changes state, which is exactly why a
tiny colon-blink change is imperceptible on the same underlying mechanism that
makes a full-screen change take ~6 seconds.

A windowed-refresh spike (recorded in
`.superpowers/sdd/2026-08-29-calclock-vista-redraw/progress.md`) confirmed this
mechanism can be exploited: constraining the SPI write to a smaller physical
window measurably speeds up the visible settle time for that window, without
requiring any change to the frame-rate register. This spec designs the real,
production implementation of that windowing.

## Goals

- Replace `RLCD_Display()`'s unconditional full-panel send, in the LVGL flush
  path, with a windowed send sized to the actual dirty area whenever that's
  worth doing.
- No visible regression: a windowed send must never corrupt panel content
  outside its intended area, and must never miss real dirty pixels (over-scan
  is fine, under-scan is not).
- Keep `RLCD_Display()` itself unchanged and available as the full-panel
  fallback: an explicit boot-sync send right after `RLCD_Init()` (so the
  panel and `DispBuffer` are known to agree before any windowed send can
  run - `RLCD_Init()`'s own `RLCD_ColorClear()` only `memset`s `DispBuffer`,
  it never sends), and the new auto-dispatch's own dimension-mismatch
  fallback path.

## Non-goals

- Re-deriving the CASET/RASET addressing itself - already hardware-confirmed
  (see below), not re-investigated here.
- Windowing the non-LVGL call sites (the boot-sync send after
  `RLCD_Init()`, etc.) - those aren't in a hot path and stay as full sends.
- Any change to the FRCTRL frame-rate register - tested, refuted, not revisited.
- Double-buffering `DispBuffer` - out of scope, unrelated to this problem.

## Confirmed hardware facts (inputs to this design)

Hardware-verified during the spike, not assumptions:

- **CASET (0x2A) = vertical (Y) axis.** Unit = 12 physical rows (3 of
  `InitLandscapeLUT()`'s `block_y` groups of 4 rows each). Full range is the
  already-in-use `0x12`-`0x2A` (18-42 = 25 units, covering the 300px height).
  Increases **downward**: CASET's low end (18-20) produced a block at the top
  of the screen, its high end (40-42) at the bottom.
- **RASET (0x2B) = horizontal (X) axis.** Unit = 2 physical columns, matching
  `byte_x` in `InitLandscapeLUT()` exactly. Full range is the already-in-use
  `0x00`-`0xC7` (0-199 = 200 units, covering the 400px width).
- **Payload size = CASET_units × RASET_units × 3 bytes.** Confirmed against
  `25 × 200 × 3 = 15000 = DisplayLen` for the full-panel case. This 3-byte
  factor corresponds exactly to `InitLandscapeLUT()`'s 3 `block_y` groups per
  CASET unit (12 rows ÷ 4 rows/group = 3).
- **An undersized RAMWR payload does not fail gracefully.** Hardware-confirmed:
  sending fewer bytes than the addressed window requires left visible garbage
  on the panel, not a clean partial fill. Getting the length exactly right is
  a correctness requirement, not an optimization.
- **`DispBuffer`'s existing layout is windowing-friendly.** It's `byte_x`-major
  (200 groups of 2 physical columns) with `block_y` (75 groups of 4 rows,
  Y-inverted) as the contiguous inner index - so for one fixed `byte_x`, a
  `block_y` sub-range is already a contiguous run in memory. No buffer
  restructure needed.

## Architecture

### New method: `RLCD_DisplayWindow`

```cpp
void DisplayPort::RLCD_DisplayWindow(int x1, int y1, int x2, int y2);
```

Takes a screen-space rectangle (inclusive, `0 <= x1 <= x2 <= 399`,
`0 <= y1 <= y2 <= 299`), rounds it to valid CASET/RASET bounds (see Rounding
below), extracts the corresponding bytes out of `DispBuffer`, and sends them
windowed. `RLCD_Display()` is unchanged and remains the full-panel path, used
directly by every non-LVGL call site and as `RLCD_DisplayWindow`'s own
fallback for near-full-screen windows.

A single private helper computes the CASET/RASET/length triple from the
rounded screen rect:

```cpp
struct RlcdWindow { uint8_t caset_xs, caset_xe, raset_ys, raset_ye; int len; };
RlcdWindow RLCD_ComputeWindow(int x1, int y1, int x2, int y2);
```

Both the payload-extraction loop and the CASET/RASET command bytes are driven
from one `RlcdWindow` value - they cannot drift apart the way the spike's own
bug did (an unmultiplied length computed separately from the command bytes).

### Rounding

**X (RASET, 2px granularity, no inversion):**

```cpp
uint8_t rs = x1 >> 1;       // round down
uint8_t re = x2 >> 1;       // x2 inclusive, integer division already floors correctly
```

**Y (CASET, 12px granularity, Y-inverted, and CASET *decreases* as screen-Y
increases):**

CASET's low end (18-20) hardware-measured at the *top* of the screen, its
high end (40-42) at the *bottom*. Since `block_y` (via `inv_y = height-1-y`)
is *largest* at the top and smallest at the bottom, CASET must be a
*decreasing* function of `block_y`: `caset = 42 - block_y/3` (verified against
both the full-panel case and a top-band example by hand below).

```cpp
int inv_y1 = height_ - 1 - y1;
int inv_y2 = height_ - 1 - y2;
int by_a = inv_y1 >> 2;
int by_b = inv_y2 >> 2;
int by_lo = std::min(by_a, by_b);
int by_hi = std::max(by_a, by_b);
int g_lo = by_lo / 3;    // group index, ascending with block_y
int g_hi = by_hi / 3;
uint8_t caset_xs = 42 - g_hi;    // larger block_y group -> smaller CASET
uint8_t caset_xe = 42 - g_lo;    // smaller block_y group -> larger CASET
```

Integer division on `g_lo`/`g_hi` already expands the window to its enclosing
12px-aligned band (a group is 3 raw `block_y` units): it can grow by up to
11px vertically, never shrinks, so it never under-scans real dirty pixels.
`RlcdWindow.len = (caset_xe - caset_xs + 1) * (re - rs + 1) * 3`.

Verified by hand: full panel (`y1=0,y2=299`) gives `by_lo=0,by_hi=74`,
`g_lo=0,g_hi=24`, `caset_xs=42-24=18`, `caset_xe=42-0=42` - matches the
existing hardcoded full-panel range exactly. A top-band rect (`y1=0,y2=33`,
the top ~34 rows) gives `by_a=74,by_b=66`, `g_lo=22,g_hi=24`,
`caset_xs=42-24=18`, `caset_xe=42-22=20` - correctly the *low* CASET end,
matching the hardware-confirmed "low CASET = top" direction.

### Buffer extraction

`DispBuffer`'s own `block_y` index always runs 0-74 ascending regardless of
what CASET means visually, so the extraction has to convert back from CASET
to that raw ascending index - using `caset_xe` (the *larger* CASET value) to
find the *start* of the contiguous run, since larger CASET corresponds to
*smaller* `block_y`/group index:

The payload is written into a **persistent scratch buffer** (`WindowBuffer`,
allocated once at full `DisplayLen` size, alongside `DispBuffer` in the
constructor) rather than a fresh `malloc`/`free` per call. `RLCD_Sendbuffera()`
queues an async DMA send and returns immediately (this is exactly the bug the
spike's own `RLCD_TestWindow` diagnostic hit: freeing a buffer right after
queuing it races the still-in-flight transfer). A persistent buffer sidesteps
this the same way `DispBuffer` itself already is safe: the *next* batch's
existing `RLCD_WaitTransferDone()` (Task 1, called before that batch's first
pixel write) guarantees any previous transfer - including one reading from
`WindowBuffer` - has completed before either buffer is touched again. No new
wait or malloc/free churn needed inside the windowed send itself.

```cpp
int H4 = height_ >> 2;   // 75, already the stride InitLandscapeLUT() uses
int cursor = 0;
int by_start = (42 - caset_xe) * 3;             // = g_lo * 3
int run_len  = (caset_xe - caset_xs + 1) * 3;
for (int bx = rs; bx <= re; bx++) {
    memcpy(WindowBuffer + cursor, &DispBuffer[bx * H4 + by_start], run_len);
    cursor += run_len;
}
```

Verified by hand against the same two cases: full panel gives
`by_start=(42-42)*3=0`, `run_len=(42-18+1)*3=75` - the entire per-`byte_x`
span, correct. The top-band rect gives `by_start=(42-20)*3=66`,
`run_len=(20-18+1)*3=9` - `block_y` 66-74, the topmost 9-row-group span,
correct.

One `memcpy` per `byte_x` column in range - `(re - rs + 1)` copies, each of a
contiguous run already sitting in `DispBuffer`.

### Fallback: dimension guard, not a coverage threshold

The original design here fell back to the existing `RLCD_Display()` above
~80% CASET-unit coverage, on the theory that a near-full window wouldn't be
worth the extraction overhead. Dropped after hardware verification: a
Main<->Cal+Clock screen switch - the actual case this was meant to help -
still fell back every time, because LVGL's own `lv_screen_load()`
invalidates close to the whole new screen regardless of any threshold value
(it doesn't diff old vs. new pixel content, it marks the whole newly-shown
screen dirty). The threshold was never shrinking anything for that case; it
just added a second code path with no measurable benefit anywhere.

`RLCD_DisplayAuto()`'s only remaining fallback is a dimension guard: if the
`DisplayPort` instance isn't the exact 400x300 landscape panel
`RLCD_ComputeWindow()`'s addressing math is hardcoded for, fall back to
`RLCD_Display()` rather than silently misaddress or overrun `DispBuffer`
through a future differently-sized panel. On this hardware that guard never
triggers - every send windows, including the near-full-panel case, at the
cost of one extra ~15000-byte `memcpy` into `WindowBuffer` before the
identical SPI send (microseconds against the multi-second settle time this
feature exists to shrink).

### Batch integration (`Lvgl_FlushCallback`, `firmware/main/main.cpp`)

Mirrors Task 1's existing `s_batch_in_progress` pattern with a per-batch union
rectangle:

```cpp
static bool s_batch_in_progress = false;
static int s_batch_x1, s_batch_y1, s_batch_x2, s_batch_y2;

if (!s_batch_in_progress) {
    // first flush of the batch: initialize the union rect from area
    s_batch_x1 = area->x1; s_batch_y1 = area->y1;
    s_batch_x2 = area->x2; s_batch_y2 = area->y2;
    s_batch_in_progress = true;
} else {
    // later flushes: widen the union rect
    s_batch_x1 = min(s_batch_x1, area->x1);  s_batch_y1 = min(s_batch_y1, area->y1);
    s_batch_x2 = max(s_batch_x2, area->x2);  s_batch_y2 = max(s_batch_y2, area->y2);
}

// on the last flush, instead of RlcdPort.RLCD_Display():
RlcdPort.RLCD_DisplayAuto(s_batch_x1, s_batch_y1, s_batch_x2, s_batch_y2);
s_batch_in_progress = false;
```

`RLCD_DisplayAuto(x1,y1,x2,y2)` is a thin new `DisplayPort` method: applies the
rounding, checks the fallback threshold, and calls either
`RLCD_DisplayWindow()` or `RLCD_Display()`. This keeps `Lvgl_FlushCallback`
itself simple - it just tracks the union rect and hands it off once per batch,
same "exactly one send per batch" shape Task 1 already established.

## Error handling / safety

- Window coordinates are clamped to `[0,399]×[0,299]` before rounding -
  defensive against any future caller passing out-of-range LVGL coordinates.
- The single `RLCD_ComputeWindow()` helper is the only place that computes
  CASET/RASET/length - both `RLCD_DisplayWindow()`'s command bytes and its
  payload-extraction loop read from the same `RlcdWindow` value, eliminating
  the class of bug the spike hit (an under-sized payload computed separately
  from the addressed window).
- `RLCD_DisplayWindow()` writes into the persistent `WindowBuffer` (not a
  fresh per-call allocation - see Buffer extraction above), so it needs no
  internal wait of its own: it follows the same async-send discipline as
  `RLCD_Display()` already does with `DispBuffer`. The caller
  (`RLCD_DisplayAuto`, itself called from the batch's last flush) relies on
  `Lvgl_FlushCallback`'s existing `RLCD_WaitTransferDone()`/`RLCD_Display()`
  pairing - no new semaphore logic needed, since there is still exactly one
  send per batch.

## Testing

- **Unit test (no hardware):** verify `RLCD_ComputeWindow()`'s rounding and
  length math against known values - the full-panel case
  `RLCD_ComputeWindow(0, 0, 399, 299)` must produce exactly
  `{caset_xs=18, caset_xe=42, raset_ys=0, raset_ye=199, len=15000}`, matching
  today's hardcoded `RLCD_Display()` constants. A handful of arbitrary rects
  (e.g. the top-bar region, a single forecast tile) checked by hand against
  the rounding rules above.
- **Hardware verification:** flash, exercise Main↔Cal+Clock screen switches
  and the hint overlay show/hide (the two symptoms that motivated this work),
  confirm no visible corruption and a visibly faster settle than the ~50px/sec
  baseline. Also re-verify the untouched cases (colon blink, focus frame)
  still look identical - this change must be invisible except for being
  faster.

## Roadmap note

Not in scope here, but worth recording: a full screen switch (Main to
Cal+Clock and back) still shows the pre-existing slow roll after this
design lands, hardware-confirmed. Not because of the fallback threshold
(dropped - see Fallback above) but because LVGL's own `lv_screen_load()`
invalidates close to the whole new screen on every switch, so the computed
window is already near-full for that specific case regardless of any
threshold. The value win from this work is on same-screen compound changes
that touch a bounded vertical band - the hint overlay (a fixed-height band
near the bottom, hardware-confirmed faster with no corruption), the top bar
(a fixed-height band at the top), and future Cal+Clock month-browsing
arrows (Task 4 of the paused Vista redraw plan). Speeding up the screen
switch itself would need a fundamentally different mechanism - real
pixel-level diffing against the previous frame's actual bytes to find the
genuinely-smaller region that visually differs, rather than trusting LVGL's
coarse "whole screen is dirty" signal - which is meaningfully more work
than this design and not attempted here.

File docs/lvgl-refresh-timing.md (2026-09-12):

# Why `Lvgl_Refresh()` Exists, and the Reference-Example Comparison

Context: this project drives the same Waveshare ESP32-S3-RLCD-4.2 board and
ST7305 panel as Waveshare's own official examples
(`ESP32-S3-RLCD-4.2/02_Example/ESP-IDF/08_LVGL_V8_Test` and
`09_LVGL_V9_Test`) and, further afield, XiaoZhi's `lcd_display.cc`. This
compares how each handles LVGL's refresh timing, and explains why this
project's `Lvgl_Refresh()` (`components/app_bsp/lvgl_bsp.cpp`) looks
different from both - written up after a 2026-08-30 investigation that
found this project had accidentally dropped a required settling delay (see
`docs/superpowers/specs/2026-08-30-windowed-partial-refresh-design.md`'s
correction note and `RLCD_PANEL_SETTLE_DELAY_MS` in `lvgl_bsp.h` for that
story).

## The Waveshare reference examples

Both `08_LVGL_V8_Test` and `09_LVGL_V9_Test` - same board, same panel, and
this project's own binary name `09_LVGL_V9_TestRLCD` all but confirms this
project started from the V9 one - define:

```c
#define LVGL_TICK_PERIOD_MS    5
#define LVGL_TASK_MAX_DELAY_MS 500
#define LVGL_TASK_MIN_DELAY_MS 50
```

They run a standing FreeRTOS task (`Lvgl_port_task`) that loops forever
calling `lv_timer_handler()`, then sleeps for whatever LVGL recommends -
clamped to **at least 50ms**. That clamp is exactly the number this
project found necessary by hardware A/B testing, completely independently.
It's not a coincidence - it's the same underlying panel requirement, baked
into Waveshare's own example as a floor on how often `lv_timer_handler()`
(and therefore a flush/`RLCD_Display()`) is allowed to fire at all. Their
flush callback has no delay of its own; the task loop's own pacing *is*
the settling delay, just structured differently than this project's.

They also use `LV_DISPLAY_RENDER_MODE_FULL` - always re-render and resend
the whole panel when anything's dirty, no partial-rect optimization at
all. So the reference examples are strictly less sophisticated than this
project on that axis (no dirty-rect batching, no windowing attempt), but
they get the timing right by construction.

## Why `Lvgl_Refresh()` exists here instead of that standing task

This project calls `esp_light_sleep_start()` in `ClockTask`'s main loop to
save power between updates (`components/clock/clock_task.c:341-342`) - a
battery-powered clock's clock task sleeps the CPU and only wakes on a
1-second timer or a button interrupt. A free-running background task
polling every 50-500ms is fundamentally incompatible with that: the CPU
could never light-sleep with another task waking up that often. So this
project traded the standard always-on task model for calling
`Lvgl_Refresh()` explicitly, only when the sleep loop wakes and something
is actually known to have changed - a deliberate, reasonable adaptation
for the power budget, not an oversight.

The cost of that trade is that the 50ms pacing the standing task gave for
free had to be reproduced explicitly - which is exactly what now sits in
`Lvgl_Refresh()` as `RLCD_PANEL_SETTLE_DELAY_MS`.

## XiaoZhi's `lcd_display.cc`

Doesn't hand-roll any of this at all - it uses Espressif's official
`esp_lvgl_port` component, which manages task/tick/timing internally.
It's the "correct, maintained library" approach in general, but it's
driving SPI/RGB/MIPI panel classes, not this reflective ST7305, so it has
no bearing on the settle-time question specifically - no equivalent quirk
to compare against.

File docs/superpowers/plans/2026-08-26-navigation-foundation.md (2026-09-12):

# Navigation Foundation Implementation Plan

> **For agentic workers:** REQUIRED SUB-SKILL: Use superpowers:subagent-driven-development (recommended) or superpowers:executing-plans to implement this plan task-by-task. Steps use checkbox (`- [ ]`) syntax for tracking.

**Goal:** Give the clock correct UTC-based timekeeping and working two-button navigation, with one shared top bar, a focus frame, and transient button hints.

**Architecture:** The RTC switches to storing UTC with the timezone applied only at display time, which also fixes DST. A dependency-free navigation state machine sits between a debouncing button layer and the screens. Shared overlay (top bar, focus frame, hint overlay) moves onto `lv_layer_top()`, which floats above whichever screen is loaded, deleting the duplicated top bar added in ccffbf5.

**Tech Stack:** ESP-IDF 5.5.5, LVGL 9.5, FreeRTOS, picolibc, Waveshare ESP32-S3-RLCD-4.2.

**Spec:** `docs/superpowers/specs/2026-08-26-widget-navigation-and-settings-design.md`

**Covers spec milestones 1-3.** Milestones 4-7 (Vista Cal+Clock redraw, weather API extension, settings/NVS, chimes) get their own plans once this lands, because they build on interfaces this plan creates.

## Global Constraints

- **1-bit panel.** `Lvgl_FlushCallback` thresholds RGB565 at `0x7fff`. No grey exists. Every stroke must be pure black (`0x000000`) and at least 2 px wide.
- **`components/ui/CMakeLists.txt` uses an explicit `SRCS` list, not a glob.** It
  used to be `file(GLOB_RECURSE ui_srcs "*.c")`, which silently misses any new
  `.c` file added without also touching `CMakeLists.txt` itself (a plain glob's
  result is cached at configure time). `CONFIGURE_DEPENDS` looks like the fix
  but ESP-IDF's component-discovery step runs in CMake script mode, where
  `CONFIGURE_DEPENDS` is rejected outright - confirmed by trying it. When a
  later task (or milestone) adds a new file under `components/ui/`, add it to
  this list by hand.
- **Refresh only when something changed.** `LV_DISPLAY_RENDER_MODE_FULL`: each `Lvgl_Refresh()` is a full 400x300 render, a 120000-iteration threshold loop, a 15 KB SPI write and a 50 ms delay.
- **LVGL heap is 64 KB** (`CONFIG_LV_MEM_SIZE_KILOBYTES=64`, built-in allocator). Watch object count.
- **LVGL timers do not run on their own.** `lv_timer_handler()` is only called from `Lvgl_Refresh()`. Anything time-based must be driven from the one-second task tick.
- **Buttons:** Select = `GPIO_NUM_18`, OK = `GPIO_NUM_0`. Active low, internal pull-up.
- **All LVGL calls must hold the lock:** `Lvgl_lock(-1)` / `Lvgl_unlock()`.
- **Screen coordinates:** 400x300. Shared overlay owns y 0..36. Screens own y 38..300.

## Build environment

This machine has no host compiler and ESP-IDF is installed via the VS Code extension, so `export.ps1` does not work. Use this PowerShell prelude for every build:

```powershell
$env:IDF_TOOLS_PATH = "C:\Espressif"
$env:IDF_PATH = "C:\esp\v5.5.5\esp-idf"
$env:ESP_ROM_ELF_DIR = "C:\Espressif\tools\esp-rom-elfs\20241011\"
$env:IDF_PYTHON_ENV_PATH = "C:\Espressif\tools\python\v5.5.5\venv"
$env:IDF_PYTHON_CHECK_CONSTRAINTS = "no"
$env:PATH = "C:\Espressif\tools\xtensa-esp-elf\esp-14.2.0_20260121\xtensa-esp-elf\bin;" +
            "C:\Espressif\tools\cmake\3.30.2\bin;C:\Espressif\tools\ninja\1.12.1\;" +
            "C:\Espressif\tools\ccache\4.12.1\ccache-4.12.1-windows-x86_64;" +
            "C:\Espressif\tools\python\v5.5.5\venv\Scripts;C:\esp\v5.5.5\esp-idf\tools;$env:PATH"
$py = "C:\Espressif\tools\python\v5.5.5\venv\Scripts\python.exe"
```

Then from `firmware/`:

- Build: `& $py "$env:IDF_PATH\tools\idf.py" build`
- Flash and watch serial: `& $py "$env:IDF_PATH\tools\idf.py" -p COM<N> flash monitor`

**There is no host C compiler**, so the test cycle is flash-and-read-serial. Tasks that can be checked without hardware also get a Python model check, which runs instantly and catches design errors before a flash cycle.

## File structure

| File | Responsibility |
|---|---|
| `components/selftest/selftest.[ch]` | Boot-time assertion harness, serial summary |
| `components/selftest/Kconfig` | `CLOCK_SELFTEST` build flag |
| `components/clock/clock_time.[ch]` | UTC to local conversion, timezone application |
| `components/clock/wifi_sync.c` | Modified: NTP returns UTC, not local |
| `components/ui/btn_event.h` | Shared `btn_event_t` enum, zero dependencies |
| `components/input/buttons.[ch]` | Debounce, long-press classification, wake sources |
| `components/ui/nav.[ch]` | Navigation state machine, pure C |
| `components/ui/overlay.[ch]` | Top bar, focus frame, hint overlay on `lv_layer_top()` |
| `components/clock/clock_task.c` | Modified: drives buttons -> nav -> screens |
| `tools/verify_nav.py` | Host-side invariant check of the transition table |

---

### Task 1: Self-test harness

The project has no test framework and no host compiler. This task builds the smallest thing that gives every later task a real red/green cycle: assertions that run at boot and print a summary over serial. Deliberately not Unity — Unity's `RUN_TEST` requires `setUp`/`tearDown` whose provision differs by ESP-IDF configuration, and 40 lines of our own has no integration risk.

**Files:**
- Create: `firmware/components/selftest/selftest.h`
- Create: `firmware/components/selftest/selftest.c`
- Create: `firmware/components/selftest/Kconfig`
- Create: `firmware/components/selftest/CMakeLists.txt`
- Modify: `firmware/main/main.cpp`
- Modify: `firmware/main/CMakeLists.txt`

**Interfaces:**
- Consumes: nothing.
- Produces: `void Selftest_Run(void)`; macros `SELFTEST_CHECK(cond)`, `SELFTEST_CHECK_INT(actual, expected)`, `SELFTEST_CHECK_STR(actual, expected)`; and the registration point `selftest_run_all()` that later tasks append their suites to.

- [ ] **Step 1: Write the harness header**

`firmware/components/selftest/selftest.h`:

```c
#pragma once

#include <stdbool.h>

#ifdef __cplusplus
extern "C" {
#endif

/* Runs every registered self-test suite and logs a summary.
   Compiles to an empty function unless CONFIG_CLOCK_SELFTEST is set. */
void Selftest_Run(void);

/* Used by suite implementations. Not for application code. */
void selftest_check(bool ok, const char *expr, const char *file, int line);
void selftest_check_int(long actual, long expected, const char *expr,
                        const char *file, int line);
void selftest_check_str(const char *actual, const char *expected,
                        const char *expr, const char *file, int line);

#define SELFTEST_CHECK(cond) \
    selftest_check((cond), #cond, __FILE__, __LINE__)
#define SELFTEST_CHECK_INT(actual, expected) \
    selftest_check_int((long)(actual), (long)(expected), #actual, __FILE__, __LINE__)
#define SELFTEST_CHECK_STR(actual, expected) \
    selftest_check_str((actual), (expected), #actual, __FILE__, __LINE__)

#ifdef __cplusplus
}
#endif
```

- [ ] **Step 2: Write the harness implementation with one deliberately failing test**

`firmware/components/selftest/selftest.c`:

```c
#include "selftest.h"

#include "esp_log.h"
#include "sdkconfig.h"

#include <string.h>

#if CONFIG_CLOCK_SELFTEST

static const char *TAG = "Selftest";

static int s_checks;
static int s_failures;

void selftest_check(bool ok, const char *expr, const char *file, int line)
{
    s_checks++;
    if (!ok) {
        s_failures++;
        ESP_LOGE(TAG, "FAIL %s:%d  %s", file, line, expr);
    }
}

void selftest_check_int(long actual, long expected, const char *expr,
                        const char *file, int line)
{
    s_checks++;
    if (actual != expected) {
        s_failures++;
        ESP_LOGE(TAG, "FAIL %s:%d  %s was %ld, expected %ld",
                 file, line, expr, actual, expected);
    }
}

void selftest_check_str(const char *actual, const char *expected,
                        const char *expr, const char *file, int line)
{
    s_checks++;
    if (actual == NULL || expected == NULL || strcmp(actual, expected) != 0) {
        s_failures++;
        ESP_LOGE(TAG, "FAIL %s:%d  %s was \"%s\", expected \"%s\"",
                 file, line, expr,
                 actual ? actual : "(null)", expected ? expected : "(null)");
    }
}

/* Proves the harness reports failures rather than silently passing.
   Removed in step 5 once it has done its job. */
static void test_harness_reports_failure(void)
{
    SELFTEST_CHECK_INT(1 + 1, 3);
}

void Selftest_Run(void)
{
    s_checks = 0;
    s_failures = 0;

    ESP_LOGI(TAG, "--- self-test start ---");
    test_harness_reports_failure();
    ESP_LOGI(TAG, "SELFTEST COMPLETE: %d check(s), %d failure(s)",
             s_checks, s_failures);
}

#else  /* !CONFIG_CLOCK_SELFTEST */

void Selftest_Run(void) {}
void selftest_check(bool ok, const char *e, const char *f, int l)
{ (void)ok; (void)e; (void)f; (void)l; }
void selftest_check_int(long a, long b, const char *e, const char *f, int l)
{ (void)a; (void)b; (void)e; (void)f; (void)l; }
void selftest_check_str(const char *a, const char *b, const char *e,
                        const char *f, int l)
{ (void)a; (void)b; (void)e; (void)f; (void)l; }

#endif
```

- [ ] **Step 3: Add the build flag and component registration**

`firmware/components/selftest/Kconfig`:

```
menu "Clock self-test"

config CLOCK_SELFTEST
    bool "Run on-device self tests at boot"
    default y
    help
        Runs assertion suites at boot, logs a summary over serial, then
        continues into the normal application. Turn this off for release
        builds.

endmenu
```

`firmware/components/selftest/CMakeLists.txt`:

```cmake
idf_component_register(
    SRCS "selftest.c"
    INCLUDE_DIRS "."
    PRIV_REQUIRES log
)
```

- [ ] **Step 4: Call it from app_main and verify the harness catches a failure**

In `firmware/main/main.cpp`, add `#include "selftest.h"` alongside the other includes, and call `Selftest_Run();` as the first statement inside `app_main()`, before `RlcdPort.RLCD_Init()`.

In `firmware/main/CMakeLists.txt`, add the dependency:

```cmake
idf_component_register(
    SRCS "main.cpp"
    INCLUDE_DIRS "./"
    PRIV_REQUIRES selftest)
```

Run: `& $py "$env:IDF_PATH\tools\idf.py" build`
Expected: builds clean.

Run: `& $py "$env:IDF_PATH\tools\idf.py" -p COM<N> flash monitor`
Expected serial output — the harness must **report the failure**, proving it is not silently passing:

```
Selftest: --- self-test start ---
Selftest: FAIL .../selftest.c:63  1 + 1 was 2, expected 3
Selftest: SELFTEST COMPLETE: 1 check(s), 1 failure(s)
```

- [ ] **Step 5: Turn the failing test green**

Change the assertion in `test_harness_reports_failure` to `SELFTEST_CHECK_INT(1 + 1, 2)` and rename the function to `test_harness_runs`.

Run: `& $py "$env:IDF_PATH\tools\idf.py" -p COM<N> flash monitor`
Expected: `SELFTEST COMPLETE: 1 check(s), 0 failure(s)`

- [ ] **Step 6: Commit**

```bash
git add firmware/components/selftest firmware/main/main.cpp firmware/main/CMakeLists.txt
git commit -m "test: add on-device self-test harness

No host compiler is available, so assertions run at boot and report over
serial. Deliberately not Unity: RUN_TEST needs setUp/tearDown whose
provision varies by IDF configuration."
```

---

### Task 2: UTC to local time conversion

**Files:**
- Create: `firmware/components/clock/clock_time.h`
- Create: `firmware/components/clock/clock_time.c`
- Create: `firmware/components/clock/clock_time_test.c`
- Modify: `firmware/components/clock/CMakeLists.txt`
- Modify: `firmware/components/selftest/selftest.c`

**Interfaces:**
- Consumes: `SELFTEST_CHECK_INT` from Task 1.
- Produces:
  - `void ClockTime_SetTimezone(const char *tz)`
  - `time_t ClockTime_UtcToEpoch(const struct tm *utc)` — does not modify `*utc`
  - `void ClockTime_UtcToLocal(const struct tm *utc, struct tm *local_out)`
  - `void ClockTime_RunTests(void)` — called by `Selftest_Run`

- [ ] **Step 1: Write the failing tests**

The expected values below are derived from the POSIX rule `EET-2EEST,M3.5.0/3,M10.5.0/4`. Standard EET is UTC+2, summer EEST is UTC+3. DST starts on the last Sunday of March at 03:00 local standard time and ends on the last Sunday of October at 04:00 local summer time — both of which are **01:00 UTC**. In 2026 the last Sunday of March is the 29th and the last Sunday of October is the 25th.

`firmware/components/clock/clock_time_test.c`:

```c
#include "clock_time.h"
#include "selftest.h"

#include <string.h>

#define TZ_KYIV "EET-2EEST,M3.5.0/3,M10.5.0/4"

static struct tm make_utc(int year, int mon, int mday, int hour, int min)
{
    struct tm t;
    memset(&t, 0, sizeof(t));
    t.tm_year = year - 1900;
    t.tm_mon  = mon - 1;
    t.tm_mday = mday;
    t.tm_hour = hour;
    t.tm_min  = min;
    return t;
}

static void check_local(const char *tz, struct tm utc,
                        int want_hour, int want_min, int want_mday)
{
    struct tm local;
    ClockTime_SetTimezone(tz);
    ClockTime_UtcToLocal(&utc, &local);
    SELFTEST_CHECK_INT(local.tm_hour, want_hour);
    SELFTEST_CHECK_INT(local.tm_min,  want_min);
    SELFTEST_CHECK_INT(local.tm_mday, want_mday);
}

void ClockTime_RunTests(void)
{
    /* Winter: EET, UTC+2 */
    check_local(TZ_KYIV, make_utc(2026, 1, 15, 12, 0), 14, 0, 15);

    /* Summer: EEST, UTC+3 */
    check_local(TZ_KYIV, make_utc(2026, 7, 15, 12, 0), 15, 0, 15);

    /* One minute before the spring transition: still EET */
    check_local(TZ_KYIV, make_utc(2026, 3, 29, 0, 59), 2, 59, 29);

    /* At the spring transition: local jumps 03:00 -> 04:00 */
    check_local(TZ_KYIV, make_utc(2026, 3, 29, 1, 0), 4, 0, 29);

    /* One minute before the autumn transition: still EEST */
    check_local(TZ_KYIV, make_utc(2026, 10, 25, 0, 59), 3, 59, 25);

    /* At the autumn transition: local falls back 04:00 -> 03:00 */
    check_local(TZ_KYIV, make_utc(2026, 10, 25, 1, 0), 3, 0, 25);

    /* UTC passes through unchanged */
    check_local("UTC0", make_utc(2026, 8, 26, 19, 3), 19, 3, 26);

    /* Conversion must not modify its input */
    struct tm utc = make_utc(2026, 8, 26, 19, 3);
    struct tm before = utc;
    (void)ClockTime_UtcToEpoch(&utc);
    SELFTEST_CHECK_INT(memcmp(&utc, &before, sizeof(utc)), 0);

    /* Epoch of a known instant: 2026-08-26 19:03:00 UTC */
    SELFTEST_CHECK_INT(ClockTime_UtcToEpoch(&before), 1787770980L);
}
```

Register it in `firmware/components/selftest/selftest.c` — but **not** via
`#include "clock_time.h"` and not via adding `clock` to selftest's
`PRIV_REQUIRES`. `clock` requires `main` (for `user_config.h`) and `main`
requires `selftest`, so `selftest -> clock` closes a cycle:
`selftest -> clock -> main -> selftest`. ESP-IDF's component build rejects
that.

Instead, forward-declare the function and call it — the prototype only has
to match; ESP-IDF links every component's objects into one binary regardless
of the declared `REQUIRES` graph, so this resolves at link time with no
header needed:

```c
/* Forward-declared rather than pulled in via "clock_time.h": see the
   comment above test_harness_runs for why. Defined in
   components/clock/clock_time_test.c. */
extern void ClockTime_RunTests(void);
```

Add that near the top of `selftest.c`, inside the `#if CONFIG_CLOCK_SELFTEST`
block, and call `ClockTime_RunTests();` inside `Selftest_Run()` immediately
after `test_harness_runs();`. `firmware/components/selftest/CMakeLists.txt`
does not change — it stays `PRIV_REQUIRES log`.

This problem is specific to `clock`: it is the only component that needs
`main` for a header. A later task's test suite (Task 5's `nav.c`, for
instance) can very likely just add its own component to `selftest`'s
`PRIV_REQUIRES` the straightforward way — `ui` does not require `main`, so
`selftest -> ui` is not cyclic. Check the target component's own
`PRIV_REQUIRES`/`REQUIRES` for `main` before assuming the straightforward
path works; if it is there, use the forward-declare pattern instead.

- [ ] **Step 2: Verify the epoch constant before trusting the test**

The value in the test must be independently confirmed, otherwise a wrong test
bakes in a wrong implementation. (This step exists for exactly this reason:
the value that was first drafted here by hand — `1787857380` — was wrong by
one full day, 86400s. Running the command below is what catches that, not
eyeballing the arithmetic.)

Run:

```bash
python -c "import calendar,datetime; print(calendar.timegm(datetime.datetime(2026,8,26,19,3,0).timetuple()))"
```

Expected: `1787770980`. If your test file has a different constant, correct
it to the printed value before continuing.

- [ ] **Step 3: Run the tests to verify they fail**

Add `"clock_time.c" "clock_time_test.c"` to the `SRCS` list in `firmware/components/clock/CMakeLists.txt` but do not create the files yet.

Run: `& $py "$env:IDF_PATH\tools\idf.py" build`
Expected: FAIL — CMake reports the missing source files. This confirms the build is actually compiling the new sources rather than ignoring them.

- [ ] **Step 4: Write the implementation**

`firmware/components/clock/clock_time.h`:

```c
#pragma once

#include <time.h>

#ifdef __cplusplus
extern "C" {
#endif

/* Applies a POSIX TZ string to every later local-time conversion. */
void ClockTime_SetTimezone(const char *tz);

/* Converts UTC calendar time to a Unix epoch. Leaves *utc untouched. */
time_t ClockTime_UtcToEpoch(const struct tm *utc);

/* Converts UTC calendar time to local time in the active timezone. */
void ClockTime_UtcToLocal(const struct tm *utc, struct tm *local_out);

/* Self-test suite. Empty unless CONFIG_CLOCK_SELFTEST. */
void ClockTime_RunTests(void);

#ifdef __cplusplus
}
#endif
```

`firmware/components/clock/clock_time.c`:

```c
#include "clock_time.h"

#include <stdlib.h>

void ClockTime_SetTimezone(const char *tz)
{
    setenv("TZ", tz, 1);
    tzset();
}

time_t ClockTime_UtcToEpoch(const struct tm *utc)
{
    /* timegm normalises its argument, so work on a copy. */
    struct tm copy = *utc;
    copy.tm_isdst = 0;
    return timegm(&copy);
}

void ClockTime_UtcToLocal(const struct tm *utc, struct tm *local_out)
{
    time_t epoch = ClockTime_UtcToEpoch(utc);
    localtime_r(&epoch, local_out);
}
```

Guard the test file so release builds drop it — wrap the entire body of `clock_time_test.c` in `#if CONFIG_CLOCK_SELFTEST` / `#else` with an empty `void ClockTime_RunTests(void) {}` / `#endif`, and add `#include "sdkconfig.h"` at the top.

- [ ] **Step 5: Run the tests to verify they pass**

Run: `& $py "$env:IDF_PATH\tools\idf.py" -p COM<N> flash monitor`
Expected: `SELFTEST COMPLETE: 24 check(s), 0 failure(s)`
(23 from this suite - seven `check_local` calls of three checks each, plus the
two direct checks - and one from the Task 1 harness test.)

If the two transition-boundary cases fail while the winter and summer cases pass, the TZ string is being parsed but the rule offsets are wrong — recheck that the rule uses `/3` and `/4` and not the default `/2`.

- [ ] **Step 6: Commit**

```bash
git add firmware/components/clock/clock_time.h firmware/components/clock/clock_time.c \
        firmware/components/clock/clock_time_test.c firmware/components/clock/CMakeLists.txt \
        firmware/components/selftest
git commit -m "feat: add UTC to local time conversion with DST tests

Covers both 2026 transition boundaries for EET/EEST, which is what the
current local-time RTC gets wrong."
```

---

### Task 3: RTC stores UTC

Fixes the bug where the clock stays an hour wrong for up to 12 hours after a DST transition, and makes a runtime timezone setting possible.

**Files:**
- Modify: `firmware/components/clock/wifi_sync.c:143` and `:60-61`
- Modify: `firmware/components/clock/wifi_sync.h`
- Modify: `firmware/components/clock/clock_task.c`

**Interfaces:**
- Consumes: `ClockTime_SetTimezone`, `ClockTime_UtcToLocal` from Task 2.
- Produces: `WifiSync_SyncTimeOnce` now writes **UTC** into `out_time`. `clock_task` holds `now_utc` and derives `now` for display.

- [ ] **Step 1: Make NTP return UTC**

In `firmware/components/clock/wifi_sync.c`, replace `localtime_r(&now, out_time);` at line 143 with:

```c
            gmtime_r(&now, out_time);
```

Update the log line immediately below it to say `"Time fetched (UTC): ..."` so serial output is not misleading.

Delete these two lines from `WifiSync_Init` (around line 60), because timezone is no longer this module's concern:

```c
    setenv("TZ", CLOCK_TIMEZONE, 1);
    tzset();
```

In `firmware/components/clock/wifi_sync.h`, document the contract change above the declaration:

```c
/* On success out_time receives the current time in UTC, not local time.
   Use ClockTime_UtcToLocal to render it. */
bool WifiSync_SyncTimeOnce(struct tm *out_time, const char *ssid, const char *password, uint32_t timeout_ms,
                            WifiSync_ConnectedCallback on_connected, void *ctx);
```

- [ ] **Step 2: Apply the timezone at startup and convert for display**

In `firmware/components/clock/clock_task.c`, add near the other includes:

```c
#include "clock_time.h"
```

At the top of `clock_task()`, before `WifiSync_Init()`, apply the compile-time timezone:

```c
    ClockTime_SetTimezone(CLOCK_TIMEZONE);
```

Rename the startup variable so the units are unmistakable. Replace:

```c
    struct tm t = {0};
```

with:

```c
    struct tm t_utc = {0};
    struct tm t = {0};
```

and after the successful `WifiSync_SyncTimeOnce(&t_utc, ...)` call, replace `Pcf85063_SetTime(&t);` with:

```c
    Pcf85063_SetTime(&t_utc);          /* the RTC now holds UTC */
    ClockTime_UtcToLocal(&t_utc, &t);  /* everything displayed is local */
```

Update the `WifiSync_SyncTimeOnce` call itself to pass `&t_utc` instead of `&t`.

- [ ] **Step 3: Convert on every read in the main loop**

In the `for (;;)` loop, replace:

```c
        struct tm now;
        if (Pcf85063_GetTime(&now) != ESP_OK) {
```

with:

```c
        struct tm now_utc;
        struct tm now;
        if (Pcf85063_GetTime(&now_utc) != ESP_OK) {
```

and immediately after the error check, add:

```c
        ClockTime_UtcToLocal(&now_utc, &now);
```

The rest of the loop keeps using `now` and needs no further change.

Inside the scheduled-sync block, replace:

```c
                struct tm ntp_t;
                if (WifiSync_SyncTimeOnce(&ntp_t, CLOCK_WIFI_SSID, CLOCK_WIFI_PASS, 15000, wifi_connected_cb, s_weather)) {
                    Pcf85063_SetTime(&ntp_t);
                    now = ntp_t;
                    update_sync_label(&now);
                }
```

with:

```c
                struct tm ntp_utc;
                if (WifiSync_SyncTimeOnce(&ntp_utc, CLOCK_WIFI_SSID, CLOCK_WIFI_PASS, 15000, wifi_connected_cb, s_weather)) {
                    Pcf85063_SetTime(&ntp_utc);
                    ClockTime_UtcToLocal(&ntp_utc, &now);
                    update_sync_label(&now);
                }
```

- [ ] **Step 4: Build and verify on hardware**

Run: `& $py "$env:IDF_PATH\tools\idf.py" build`
Expected: builds clean, no warnings.

Run: `& $py "$env:IDF_PATH\tools\idf.py" -p COM<N> flash monitor`

Expected, in order:
1. `Time fetched (UTC): HH:MM:SS ...` where `HH` is **two or three hours behind** your wall clock (two in winter, three in summer).
2. The display shows your correct **local** wall-clock time.

If the display shows UTC, `ClockTime_UtcToLocal` is not being applied on the read path. If the display is correct but the log shows local time, step 1 did not take effect.

- [ ] **Step 5: Verify the RTC survives a reset**

Press the reset button (do not reflash) and watch the serial log. Because Wi-Fi sync runs at boot the clock will resync, so to test the RTC path specifically, temporarily set `CLOCK_WIFI_SSID` to a nonexistent network, flash, and confirm the boot path reports no Wi-Fi. Then restore the real SSID.

Expected: the failure path is reached and reported, confirming the RTC read path is exercised independently of NTP.

- [ ] **Step 6: Commit**

```bash
git add firmware/components/clock/wifi_sync.c firmware/components/clock/wifi_sync.h \
        firmware/components/clock/clock_task.c
git commit -m "fix: store UTC in the RTC, apply timezone only for display

Pcf85063_SetTime was being handed local time, so DST transitions did not
take effect until the next NTP sync - up to 12 hours late. It also made a
runtime timezone setting impossible."
```

---

### Task 4: Two-button input layer

**Files:**
- Create: `firmware/components/ui/btn_event.h`
- Create: `firmware/components/input/buttons.h`
- Create: `firmware/components/input/buttons.c`
- Create: `firmware/components/input/CMakeLists.txt`
- Modify: `firmware/main/user_config.h`

**Interfaces:**
- Consumes: nothing.
- Produces:
  - `btn_event_t` enum: `BTN_EV_NONE`, `BTN_EV_SELECT_SHORT`, `BTN_EV_SELECT_LONG`, `BTN_EV_OK_SHORT`, `BTN_EV_OK_LONG`
  - `void Buttons_Init(gpio_num_t select_pin, gpio_num_t ok_pin)`
  - `void Buttons_EnableWakeup(void)`
  - `btn_event_t Buttons_ReadEvent(void)`

- [ ] **Step 1: Define the shared event type**

`btn_event_t` lives in its own header so that `nav` (Task 5) can consume it without depending on the GPIO layer.

`firmware/components/ui/btn_event.h`:

```c
#pragma once

#ifdef __cplusplus
extern "C" {
#endif

typedef enum {
    BTN_EV_NONE = 0,
    BTN_EV_SELECT_SHORT,
    BTN_EV_SELECT_LONG,
    BTN_EV_OK_SHORT,
    BTN_EV_OK_LONG,
} btn_event_t;

#ifdef __cplusplus
}
#endif
```

- [ ] **Step 2: Add the pins**

In `firmware/main/user_config.h`, replace the `KEY_BUTTON_PIN` line with:

```c
#define BTN_OK_PIN          GPIO_NUM_0    /* BOOT  */
#define BTN_SELECT_PIN      GPIO_NUM_18   /* KEY   */
```

Both values are confirmed against the esp32s3-rlcd-smart-clock project on this same board, which uses `ButtonInput s_buttons(GPIO_NUM_18, GPIO_NUM_0)` with select first.

- [ ] **Step 3: Write the button layer**

`firmware/components/input/buttons.h`:

```c
#pragma once

#include "btn_event.h"
#include "driver/gpio.h"

#ifdef __cplusplus
extern "C" {
#endif

/* Configures both pins as inputs with internal pull-ups. Active low. */
void Buttons_Init(gpio_num_t select_pin, gpio_num_t ok_pin);

/* Arms both pins as light-sleep wake sources. Call once after Init. */
void Buttons_EnableWakeup(void);

/* Call after waking with ESP_SLEEP_WAKEUP_GPIO. Debounces, classifies the
   press, then blocks until release so one push cannot emit twice.
   Returns BTN_EV_NONE if no button was actually down. */
btn_event_t Buttons_ReadEvent(void);

#ifdef __cplusplus
}
#endif
```

`firmware/components/input/buttons.c`:

```c
#include "buttons.h"

#include "freertos/FreeRTOS.h"
#include "freertos/task.h"
#include "esp_sleep.h"

#define BTN_DEBOUNCE_MS 20
#define BTN_LONG_MS     600
#define BTN_POLL_MS     20

static gpio_num_t s_select = GPIO_NUM_NC;
static gpio_num_t s_ok     = GPIO_NUM_NC;

void Buttons_Init(gpio_num_t select_pin, gpio_num_t ok_pin)
{
    s_select = select_pin;
    s_ok     = ok_pin;

    gpio_config_t cfg = {
        .pin_bit_mask = (1ULL << select_pin) | (1ULL << ok_pin),
        .mode         = GPIO_MODE_INPUT,
        .pull_up_en   = GPIO_PULLUP_ENABLE,
        .pull_down_en = GPIO_PULLDOWN_DISABLE,
        .intr_type    = GPIO_INTR_DISABLE,
    };
    gpio_config(&cfg);
}

void Buttons_EnableWakeup(void)
{
    gpio_wakeup_enable(s_select, GPIO_INTR_LOW_LEVEL);
    gpio_wakeup_enable(s_ok, GPIO_INTR_LOW_LEVEL);
    esp_sleep_enable_gpio_wakeup();
}

btn_event_t Buttons_ReadEvent(void)
{
    vTaskDelay(pdMS_TO_TICKS(BTN_DEBOUNCE_MS));

    bool select_down = gpio_get_level(s_select) == 0;
    bool ok_down     = gpio_get_level(s_ok) == 0;
    if (!select_down && !ok_down) {
        return BTN_EV_NONE;   /* bounce or a wake from something else */
    }

    /* If somehow both are down, Select wins. */
    const bool       is_select = select_down;
    const gpio_num_t pin       = is_select ? s_select : s_ok;

    int held_ms = BTN_DEBOUNCE_MS;
    while (gpio_get_level(pin) == 0 && held_ms < BTN_LONG_MS) {
        vTaskDelay(pdMS_TO_TICKS(BTN_POLL_MS));
        held_ms += BTN_POLL_MS;
    }

    const bool is_long = held_ms >= BTN_LONG_MS;

    /* Drain the remainder of the press. */
    while (gpio_get_level(pin) == 0) {
        vTaskDelay(pdMS_TO_TICKS(BTN_POLL_MS));
    }

    if (is_select) {
        return is_long ? BTN_EV_SELECT_LONG : BTN_EV_SELECT_SHORT;
    }
    return is_long ? BTN_EV_OK_LONG : BTN_EV_OK_SHORT;
}
```

`firmware/components/input/CMakeLists.txt`:

```cmake
idf_component_register(
    SRCS "buttons.c"
    INCLUDE_DIRS "."
    PRIV_REQUIRES driver esp_hw_support
    REQUIRES ui
)
```

`REQUIRES ui` is what makes `btn_event.h` visible, since it lives in the `ui` component's include directory.

- [ ] **Step 4: Verify both buttons on hardware**

This is the first time GPIO18 is exercised on this board, so prove it before building navigation on top of it. Temporarily add to `clock_task()`, immediately after `configure_key_button_wakeup()` is replaced (Task 8 does the full wiring — for now add a throwaway probe loop at the top of `clock_task`):

```c
    Buttons_Init(BTN_SELECT_PIN, BTN_OK_PIN);
    for (int i = 0; i < 200; i++) {
        ESP_LOGI(TAG, "probe select=%d ok=%d",
                 gpio_get_level(BTN_SELECT_PIN), gpio_get_level(BTN_OK_PIN));
        vTaskDelay(pdMS_TO_TICKS(100));
    }
```

Run: `& $py "$env:IDF_PATH\tools\idf.py" -p COM<N> flash monitor`

Press each of the two non-power buttons in turn. Expected: `select` reads 0 while one is held and `ok` reads 0 while the other is held; both read 1 at rest.

**If neither line ever drops to 0 for one of the buttons, stop and report it** — the Select pin is wrong and every later task depends on it. Delete the probe loop once confirmed.

- [ ] **Step 5: Commit**

```bash
git add firmware/components/input firmware/components/ui/btn_event.h firmware/main/user_config.h
git commit -m "feat: add two-button input layer with long-press detection

Select on GPIO18, OK on GPIO0, both confirmed against the smart-clock
project on this board."
```

---
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

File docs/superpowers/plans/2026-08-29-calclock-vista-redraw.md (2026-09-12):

# Cal+Clock Vista Redraw Implementation Plan

> **For agentic workers:** REQUIRED SUB-SKILL: Use superpowers:subagent-driven-development (recommended) or superpowers:executing-plans to implement this plan task-by-task. Steps use checkbox (`- [ ]`) syntax for tracking.

**Goal:** Redraw the existing Cal+Clock screen as a plain-Vista analog dial with a working second hand and month browsing, give the shared top bar and Cal+Clock's bezel/buttons a dithered metal look, and replace the SPI flush path's blind 50 ms delay with an accurate completion wait.

**Architecture:** No screens are added and no `nav.c` change is needed — Cal+Clock stays the second top-level screen it already is. The dial gets a second hand and finer ticks; the calendar grid moves from one multi-line label per column to one label per cell so leading/trailing days can use a smaller font; `<`/`>` month-browsing reuses `nav.c`'s existing FOCUS/DETAIL machinery the same way Settings already does ("caller acts, then bounces back to FOCUS"). The shared top bar and Cal+Clock's own bezel/buttons get a Bayer-dithered metal treatment, gated on an early hardware check that dithered pixels don't bleed. The SPI panel driver gets a real completion callback in place of a padded delay.

**Tech Stack:** ESP-IDF 5.5.5, LVGL 9.5, FreeRTOS, picolibc, Waveshare ESP32-S3-RLCD-4.2.

**Spec:** `docs/superpowers/specs/2026-08-29-calclock-vista-redraw-design.md`

**Covers milestone 4** of `docs/superpowers/specs/2026-08-26-widget-navigation-and-settings-design.md`, refined into its own spec the same way milestones 1-3 became `docs/superpowers/plans/2026-08-26-navigation-foundation.md`. Milestones 5-7 (weather API extension, Settings/NVS, chimes) get their own plans once this lands.

## Global Constraints

- **1-bit panel.** `Lvgl_FlushCallback` thresholds RGB565 at `0x7fff`. No grey exists. Every stroke must be pure black (`0x000000`) and at least 2 px wide.
- **`components/ui/CMakeLists.txt` uses an explicit `SRCS` list, not a glob.** Add any new file under `components/ui/` to it by hand.
- **LVGL heap is 64 KB** (`CONFIG_LV_MEM_SIZE_KILOBYTES=64`, built-in allocator). Watch object count — the grid rework alone adds 35 new label objects (42 day cells minus the 7 that already exist as column headers).
- **LVGL timers do not run on their own.** `lv_timer_handler()` is only called from `Lvgl_Refresh()`. Anything time-based must be driven from the one-second task tick.
- **Buttons:** Select = `GPIO_NUM_18`, OK = `GPIO_NUM_0`. Active low, internal pull-up.
- **All LVGL calls must hold the lock:** `Lvgl_lock(-1)` / `Lvgl_unlock()`.
- **Screen coordinates:** 400x300. Shared overlay owns y 0..36. Screens own y 38..300.
- **`nav.c` has no backward-navigation event.** `SELECT_SHORT` only ever moves focus forward with wrap. Month browsing (Task 4) works around this without touching `nav.c` — see that task.
- **`DispBuffer` (`components/port_bsp/display_bsp.cpp`) is single-buffered.** Writing to it while a previous SPI transfer is still in flight is a data race. Task 1 fixes the only place this was informally protected (a padded delay) with a real wait; every later task that touches drawing code relies on that wait already being in place and must not reintroduce a blind delay.

## Build environment

Same as `docs/superpowers/plans/2026-08-26-navigation-foundation.md`'s "Build environment" section — reuse that PowerShell prelude verbatim. From `firmware/`:

- Build: `& $py "$env:IDF_PATH\tools\idf.py" build`
- Flash: `& $py "$env:IDF_PATH\tools\idf.py" -p COM<N> flash`

There is no host C compiler for the LVGL/ESP-IDF side, so hardware verification is flash-and-look, same as every prior task in this project. The font-metrics check in Task 6 is host-side Python, like `tools/verify_nav.py`, and runs instantly.

## File structure

| File | Responsibility |
|---|---|
| `components/port_bsp/display_bsp.[h,cpp]` | Modified: real SPI transfer-done wait, replacing the blind delay |
| `components/app_bsp/lvgl_bsp.cpp` | Modified: drop the `vTaskDelay(50)` |
| `main/main.cpp` | Modified: `Lvgl_FlushCallback` waits before writing pixels |
| `components/ui/dither.[h,c]` | New: Bayer 4x4 ordered-dither helper, shared by the hardware test pattern and the real header rail/bezel/button rendering |
| `components/ui/overlay.c` | Modified: shared top bar becomes a dithered metal rail with recessed plaques |
| `components/ui/screens.c` | Modified: dial gets a second hand and 60 minor ticks; calendar grid becomes per-cell; `<`/`>` month-browsing arrows; bezel and arrow dithering |
| `components/clock/clock_task.c` | Modified: `nav_focus_count` for Cal+Clock, its focus-area geometry, the DETAIL-bounce month-shift handler, `update_clock_hands`'s new `second` parameter threaded through |
| `tools/verify_calendar_layout.py` | New: host-side check of grid/dial/rail geometry against real LVGL font metrics, parsed from the compiled font `.c` sources |

---

### Task 1: Accurate SPI transfer wait

**Files:**
- Modify: `firmware/components/port_bsp/display_bsp.h`
- Modify: `firmware/components/port_bsp/display_bsp.cpp`
- Modify: `firmware/components/app_bsp/lvgl_bsp.cpp:37`
- Modify: `firmware/main/main.cpp:17-31`

**Interfaces:**
- Consumes: nothing new.
- Produces: `void DisplayPort::RLCD_WaitTransferDone()` — blocks until any SPI color transfer already in flight has completed. Later tasks that add drawing code must not need to know this exists; it is called once, at the top of `Lvgl_FlushCallback`, and nowhere else.

- [ ] **Step 1: Add the semaphore and the wait method**

In `firmware/components/port_bsp/display_bsp.h`, add to the includes:

```cpp
#include <freertos/FreeRTOS.h>
#include <freertos/semphr.h>
```

Add to the private section, after `int DisplayLen;`:

```cpp
    SemaphoreHandle_t xfer_done_ = NULL;
    static bool on_color_trans_done(esp_lcd_panel_io_handle_t panel_io,
                                    esp_lcd_panel_io_event_data_t *edata,
                                    void *user_ctx);
```

Add to the public section, after `void RLCD_Display();`:

```cpp
    void RLCD_WaitTransferDone();
```

- [ ] **Step 2: Create the semaphore and register the callback**

In `firmware/components/port_bsp/display_bsp.cpp`, in the constructor, immediately after
`ESP_ERROR_CHECK(esp_lcd_new_panel_io_spi((esp_lcd_spi_bus_handle_t)spihost, &io_config, &io_handle));`:

```cpp
    xfer_done_ = xSemaphoreCreateBinary();
    assert(xfer_done_);
    xSemaphoreGive(xfer_done_);   /* nothing in flight yet */

    esp_lcd_panel_io_callbacks_t cbs = {};
    cbs.on_color_trans_done = &DisplayPort::on_color_trans_done;
    ESP_ERROR_CHECK(esp_lcd_panel_io_register_event_callbacks(io_handle, &cbs, this));
```

- [ ] **Step 3: Implement the callback and the wait method**

Add near `RLCD_Sendbuffera`:

```cpp
bool DisplayPort::on_color_trans_done(esp_lcd_panel_io_handle_t panel_io,
                                      esp_lcd_panel_io_event_data_t *edata,
                                      void *user_ctx)
{
    DisplayPort *self = static_cast<DisplayPort *>(user_ctx);
    BaseType_t high_task_awoken = pdFALSE;
    xSemaphoreGiveFromISR(self->xfer_done_, &high_task_awoken);
    return high_task_awoken == pdTRUE;
}

void DisplayPort::RLCD_WaitTransferDone()
{
    xSemaphoreTake(xfer_done_, portMAX_DELAY);
}
```

- [ ] **Step 4: Move the wait to before the pixel writes, not before the send**

In `firmware/main/main.cpp`, `Lvgl_FlushCallback` currently reads:

```cpp
static void Lvgl_FlushCallback(lv_display_t *drv, const lv_area_t *area, uint8_t *color_map)
{
    uint16_t *buffer = (uint16_t *)color_map;
    for (int y = area->y1; y <= area->y2; y++)
    {
        for (int x = area->x1; x <= area->x2; x++)
        {
            uint8_t color = (*buffer < 0x7fff) ? ColorBlack : ColorWhite;
            RlcdPort.RLCD_SetPixel(x, y, color);
            buffer++;
        }
    }
    RlcdPort.RLCD_Display();
    lv_disp_flush_ready(drv);
}
```

Change it to wait first — this is the fix, not the send:

```cpp
static void Lvgl_FlushCallback(lv_display_t *drv, const lv_area_t *area, uint8_t *color_map)
{
    RlcdPort.RLCD_WaitTransferDone();

    uint16_t *buffer = (uint16_t *)color_map;
    for (int y = area->y1; y <= area->y2; y++)
    {
        for (int x = area->x1; x <= area->x2; x++)
        {
            uint8_t color = (*buffer < 0x7fff) ? ColorBlack : ColorWhite;
            RlcdPort.RLCD_SetPixel(x, y, color);
            buffer++;
        }
    }
    RlcdPort.RLCD_Display();
    lv_disp_flush_ready(drv);
}
```

- [ ] **Step 5: Drop the blind delay**

In `firmware/components/app_bsp/lvgl_bsp.cpp`, `Lvgl_Refresh()` currently ends with:

```c
    lv_tick_inc(elapsed_ms);
    lv_timer_handler();
    lv_refr_now(NULL);

    vTaskDelay(pdMS_TO_TICKS(50));
}
```

Remove the `vTaskDelay` line:

```c
    lv_tick_inc(elapsed_ms);
    lv_timer_handler();
    lv_refr_now(NULL);
}
```

- [ ] **Step 6: Build and verify on hardware**

Run: `& $py "$env:IDF_PATH\tools\idf.py" build`
Expected: builds clean.

Flash and confirm: Main and Cal+Clock still render correctly (top bar, clock digits, colon blink, forecast tiles), and the focus frame / hint overlay from the navigation-foundation work still behave exactly as before. This is a timing-only change — "looks and feels identical, if anything snappier" is the bar. No visual regression is acceptable; if anything looks wrong (torn frames, missing content), the wait is in the wrong place and Step 4 needs revisiting before proceeding to any other task, since every later task's drawing code depends on this being correct.

- [ ] **Step 7: Commit**

```bash
git add firmware/components/port_bsp/display_bsp.h firmware/components/port_bsp/display_bsp.cpp \
       firmware/components/app_bsp/lvgl_bsp.cpp firmware/main/main.cpp
git commit -m "fix: wait for the actual SPI transfer instead of a padded delay

Lvgl_FlushCallback now waits on a real on_color_trans_done completion
signal before writing this frame's pixels, replacing a blind 50ms
vTaskDelay that was informally protecting DispBuffer (single-buffered,
not safe to mutate while a previous transfer is still in flight) against
a race it never actually proved safe against."
```

---
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

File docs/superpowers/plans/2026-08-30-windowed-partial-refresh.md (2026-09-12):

# Windowed Partial Refresh Implementation Plan

> **Outcome (2026-08-30):** implemented, hardware-tested across three policy
> variants, and reverted - windowing never reliably reduced the roll this
> plan was written to fix. The actual root cause (a settling delay removed
> by an earlier, unrelated fix) was found and corrected separately; see the
> correction note at the top of this plan's spec
> (`docs/superpowers/specs/2026-08-30-windowed-partial-refresh-design.md`)
> and commit `04e0c4e`. Kept as a historical record only.

> **For agentic workers:** REQUIRED SUB-SKILL: Use superpowers:subagent-driven-development (recommended) or superpowers:executing-plans to implement this plan task-by-task. Steps use checkbox (`- [ ]`) syntax for tracking.

**Goal:** Replace the ST7305 panel's unconditional full-frame SPI send in the LVGL flush path with a windowed send sized to the actual dirty area, so small/localized UI changes settle visibly faster than the ~50px/sec full-panel roll.

**Architecture:** A pure, unit-testable `RLCD_ComputeWindow()` function converts a screen-space rectangle into hardware-valid CASET/RASET bounds and a matching payload length. `RLCD_DisplayWindow()` extracts the corresponding bytes out of the existing `DispBuffer` into a new persistent `WindowBuffer` and sends them windowed. `RLCD_DisplayAuto()` picks between the windowed path and the existing full-panel `RLCD_Display()` based on how much of the panel a given update covers. `Lvgl_FlushCallback` tracks the union of everything painted in one refresh pass and hands it to `RLCD_DisplayAuto()` exactly once per batch, replacing its current unconditional `RLCD_Display()` call.

**Tech Stack:** ESP-IDF 5.5.5, LVGL 9.5, C++ (DisplayPort class), this project's existing `selftest`-based test harness (device-boot-time assertions logged over UART, no host-side test runner).

**Spec:** `docs/superpowers/specs/2026-08-30-windowed-partial-refresh-design.md`
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

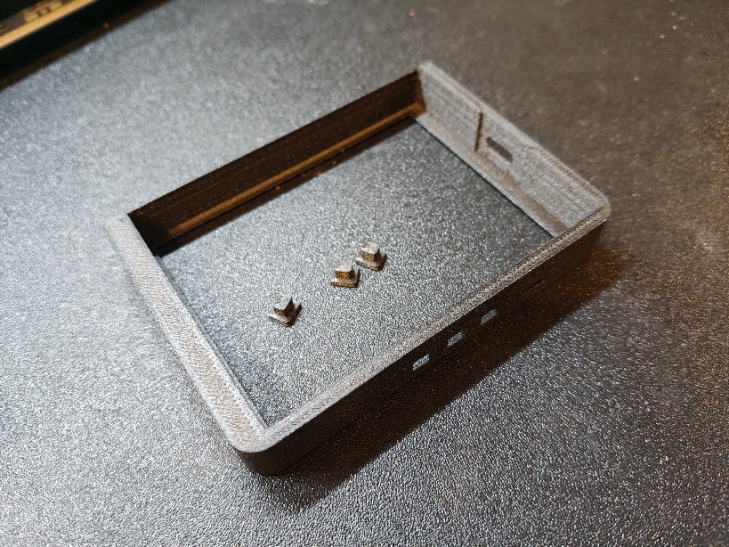
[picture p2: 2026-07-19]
img/3d_case.jpg

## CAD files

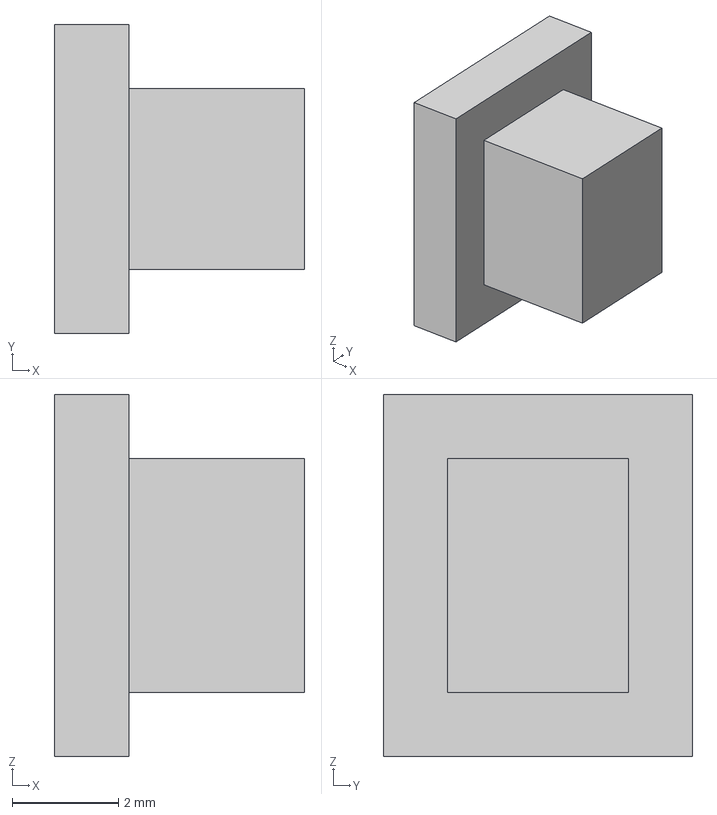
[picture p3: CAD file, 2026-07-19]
3d/button.3mf
4.70 x 5.80 x 6.80 mm

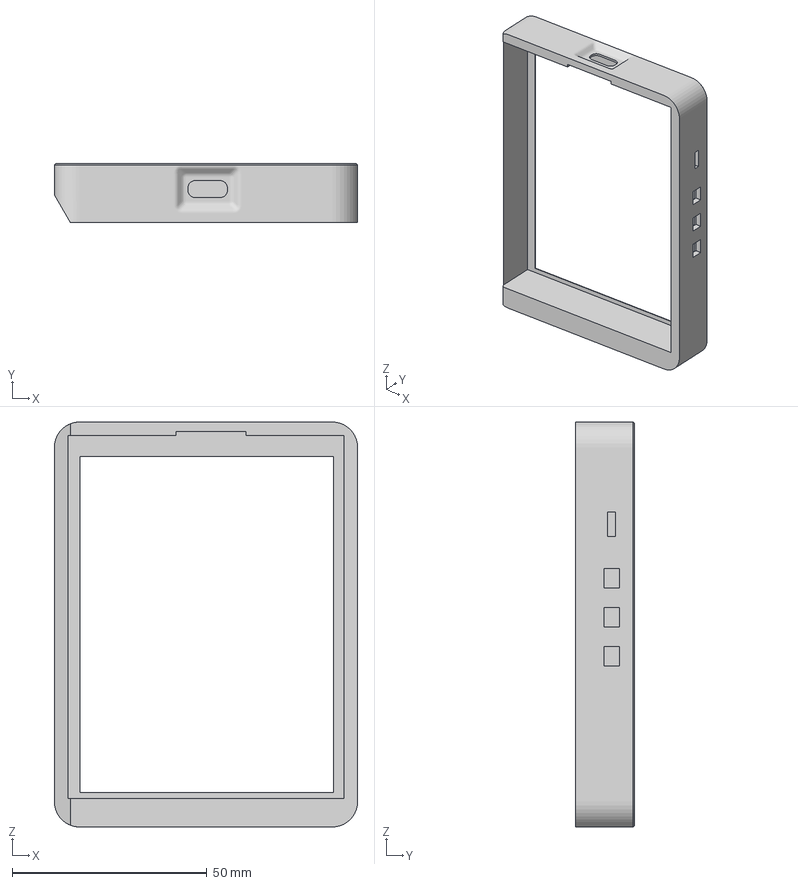
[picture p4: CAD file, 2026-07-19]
3d/case.3mf
77.8 x 15.2 x 103.9 mm

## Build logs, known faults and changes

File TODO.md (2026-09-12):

# Roadmap and open leads

The design work lives in `docs/superpowers/specs/`; this file is the index of
what is left, not a replacement for it. Anything marked **specced** has a
written design already — read it before starting, it carries decisions that are
not obvious from the code.

## Planned milestones

From `docs/superpowers/specs/2026-08-26-widget-navigation-and-settings-design.md`.
Milestones 1–4 are shipped: RTC stores UTC, input layer and nav state machine,
shared overlay on `lv_layer_top()`, and the Cal+Clock Vista redraw with the
dial, month browsing and the digital readout on the face.

### 5. Weather API extension, sun and moon — **specced** (§"Sun and moon", §"Weather API extension")

Three more daily fields at **no extra network cost** — the request is already
being made:

```
&daily=weathercode,temperature_2m_max,temperature_2m_min,
       sunrise,sunset,precipitation_probability_max,wind_speed_10m_max
```

`WeatherDay` gains `sunrise_min`, `sunset_min` (minutes past local midnight),
`precip_prob`, `wind_max`. `timezone=auto` is already set, so the returned sun
times are local.

Moon phase is computed locally, no network:

```
phase = frac((jd - 2451550.1) / 29.530588853)    /* ref new moon 2000-01-06 */
illum = (1 - cos(2*pi*phase)) / 2
```

Named across eight buckets. Currently `weather.c` fetches only the three
original fields and `WeatherDay` has no sun/moon members at all.

### 6. Settings screen and NVS — **specced** (§"Settings", §"NVS schema")

`NAV_SETTINGS` exists in the nav state machine and is covered by `nav_test.c`,
but there is no screen behind it. One scrolling list: Select moves the row, OK
cycles the value or runs the action, long Select exits.

- **Display** — 24h/12h · date format (Weekday `Fri 26 Aug` default / `DD.MM.YYYY`
  / `YYYY-MM-DD` / `MM/DD/YYYY`) · °C/°F · seconds on/off · week starts Mon/Sun
- **Time** — timezone from a preset POSIX-TZ table · sync hour 1 · sync hour 2
- **Actions** — sync weather now · sync time now · reboot
- **Info** (read-only) — firmware version · uptime · battery mV and % · free
  LVGL heap, internal heap, PSRAM · SSID and RSSI · last NTP sync · RTC state

Note the spec predates the Kconfig migration: several of these now also exist
as build-time options under **Weather Clock**. Decide per row whether NVS
overrides Kconfig or replaces it — the spec does not answer that.

The 3-letter month table the Weekday format needs does not exist anywhere in
the firmware yet; `WEEKDAY_NAMES` in `clock_task.c` is the closest thing.

### 7. Chimes — **specced** (§"Chimes", §"Timbre", §"What plays", §"Scheduling")

Synthesised Westminster quarters plus the hour strike, through the ES8311
codec. Nothing exists in the tree: no `chime`, no `es8311`, no audio task.

Risks the spec already calls out, worth re-reading before starting:

- **A speaker may not be fitted** — the board only provides a header. Chimes
  default to off, the ES8311 is probed over I2C at boot, and the rows render as
  "no audio hardware" rather than failing if it does not answer.
- **Playback is long** — Westminster on the hour plus twelve strikes runs about
  45 s, so it needs its own task and must never block the display tick.

## Backlog, not yet designed

- **Web interface.** Discussed but never specced — there is no design document
  for it. Needs its own brainstorm: what it serves (settings? readings? OTA?),
  whether the radio stays up for it or it is on-demand, and what that does to
  the power budget, which currently assumes Wi-Fi is down except for a few
  seconds a day.
- **A weather-station screen.** From the Cal+Clock spec's roadmap note: a new
  top-level screen with live current conditions, an hourly forecast, and an
  analogue clock styled after a classic instrument. New API surface, new screen
  in `nav.c`, new visual language — its own brainstorm when its turn comes.
- **The Cal+Clock bottom strip.** The four-day forecast row at `CAL_FC_Y` is
  the obvious place for Google Calendar events, or for the sun/moon strip from
  milestone 5. Those two want the same space, so decide between them rather
  than discovering the collision mid-implementation.
- **Trend arrows** for indoor temperature and humidity — space is already
  reserved at x68 and x159, but nothing stores previous readings, so reading
  history has to be plumbed first.
- **Dithered ghost digits** for adjacent-month calendar cells. They currently
  render a font size down, which works but is not what the spec pictured.

## Unverified

- **The `--:--` path.** A cold boot with no network shows dashes instead of a
  confident wrong time. The logic is exercised, the display is not: raising the
  PCF85063's oscillator-stop flag needs a real power cycle, and USB keeps the
  board powered.

## Closed 2026-09-12: free DRAM falling per *failed* Wi-Fi connect

Kept as a worked example. This was recorded as a real lead — free internal DRAM
fell ~1.8 KB per failed bring-up across five cycles (-1836, -1816, -1892 B) —
and it read like a leak in the failed-connect path, the one path
`wifi_stress.c` never exercised.

It was not a separate leak. It was the per-tick `setenv` leak in
`ClockTime_UtcToEpoch`, fixed in `80d61b1`, seen through a minute that happened
to contain a failed connect. At the measured 2160 B/minute — 36 B/s — those
three figures are 51, 50 and 53 seconds of ticks. A failed connect blocks the
1 Hz loop for three 15 s attempts plus teardown, so such a minute holds fewer
than sixty conversions. That is why it read *below* the steady rate, and so did
not look like the same thing.

The decline was real, the rate was real, the attribution was wrong.

## Method notes worth keeping

Two measurement mistakes cost most of a day between them, and both are the same
shape: trusting a number without checking what it was actually measuring.

1. **`heap_trace_stop()` before a settle** reports every `TIME_WAIT` socket as a
   leak, with a convincing call stack, at any settle length. If the number does
   not move when you change the measurement, suspect the measurement. See
   `34702d3` on the branch history.
2. **Ground-truth a heap claim against the subsystem's own bookkeeping.** lwIP
   keeps `tcp_active_pcbs` / `tcp_tw_pcbs` / `tcp_bound_pcbs`; walking them
   settled in one run what three heap traces got wrong.
3. **A backtrace cannot cross a thread boundary.** `netconn_new` posts a message
   and lwIP's `tcpip` thread allocates, so the stack ends there no matter how
   large `CONFIG_HEAP_TRACING_STACK_DEPTH` is.
4. **Dumping a few hundred trace records over USB serial trips the interrupt
   watchdog.** Keep the window short and expect the reboot.
5. **The per-minute heap line in `clock_task.c` is the canary.** It made a
   2160 B/minute leak visible in one capture. Leave it in.

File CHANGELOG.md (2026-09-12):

# Changelog

Notable changes to this project. Format loosely follows
[Keep a Changelog](https://keepachangelog.com/en/1.1.0/).

Dates are when the work landed on the branch, not when it was released.

## [Unreleased] — the `calendar-screen-rework` branch

99 commits. The display and reliability work is finished and
hardware-verified. The reboot that ran through most of this branch's history is
found and fixed — see **Fixed**, first entry — and nothing is left under
[Known issues](#known-issues). One display path remains
[Unverified](#unverified) because reproducing it needs a real power cycle.

### Added

**Calendar + clock screen.** A Monday-first month grid with today boxed and
adjacent-month days rendered a size down, an analogue dial beside it, the
four-day forecast underneath and a quote strip at the foot. Arrow buttons page
through months. One label per day cell rather than one per column, because a
single `lv_label` cannot mix fonts and the adjacent-month days need a smaller
one.

**Analogue dial** with hour, minute and second hands, 12 solid hour ticks and 60
minor ticks. The minor ticks are dithered to a mid-grey in screen space, since
the panel has no grey of its own.

**Five-slot top bar** — indoor temperature, humidity, current weather, link
status, battery — living on `lv_layer_top()`, so it is drawn over every screen
rather than belonging to any one of them.

**Date on the clock face**, in the gap between the colon's two dots: the one
hole the big digits leave. Stacked weekday over day number.

**Current outdoor conditions**, not just the forecast high — `current_weather=true`
on the Open-Meteo request plus a `WeatherNow` field. Weather now runs on its own
cycle (`CONFIG_WEATHER_REFRESH_MIN`, 30 minutes) instead of riding the
twice-daily time sync.

**Battery fuel gauge** with the voltage beside it, and a charging bolt shown
*instead of* the fill — on a 1-bit panel a glyph drawn over a solid black fill
is invisible.

**Link status indicator** with four states: a tick when the last sync worked and
the radio is resting, a warning when the data has gone stale, a refresh while
associating, and an aerial only once an address is actually held.

**Button navigation** — a two-button input layer with long-press detection, a
navigation state machine, and a focus frame and hint overlay.

**Diagnostics.** Core dumps written to flash, so an intermittent panic can be
read afterwards. A live status line carrying last sync, uptime to the minute,
reset reason (with the raw ROM code, since IDF collapses both USB causes into
one) and heap. Per-sync internal-heap logging. `alloc_watch`, which records the
size and caps of a failed allocation plus a heap snapshot taken before every
Wi-Fi bring-up, in `RTC_NOINIT` so both survive the reboot.

**Tests and tooling.** An on-device self-test harness. `tools/verify_calendar_layout.py`,
which measures layouts against the real LVGL font tables — parsing `adv_w` out of
the generated font C files, including the sparse ranges where `°` and the
`LV_SYMBOL_*` glyphs live — and tests the widest value each field can hold.
`wifi_stress.c`, a Kconfig-gated bring-up/fetch stress test with a walker over
lwIP's own PCB lists. `tools/render_screen_mockup.py`, which draws both screens
as SVG from the layout constants themselves.

### Changed

**All configuration moved into Kconfig** under **Weather Clock**.
`clock_config.h` and `weather_config.h` are gone, and `sdkconfig` is no longer
tracked, because it holds the Wi-Fi password and the location.

**Stays awake while a USB host is attached.** Light sleep suspends the USB
Serial/JTAG peripheral, which made the port vanish; this turned 206 consecutive
flash failures into first-try success and made serial usable as a diagnostic
channel again. On battery it sleeps as before.

**TLS buffers are allocated per transfer**, raising the measured memory floor by
about 16.7 KB.

**Wi-Fi bring-up is declined below a heap floor** (`CONFIG_CLOCK_MIN_HEAP_FOR_WIFI`,
57344 B) rather than risking an abort deep inside the PHY. Measured free before
bring-up is ~145 KB, so the floor has 2.5x of headroom.

**The repository was flattened**, `firmware/` into the root.

**The README's screenshots are generated, not photographed.** The old photo
predated two redesigns and still showed the date on the top bar. Both screens
are now drawn from the layout constants, so they cannot quietly go stale.

### Fixed

**The clock tick leaked 32 bytes a second, and that was the reboot.**
`ClockTime_UtcToEpoch` took a UTC epoch out of newlib the obvious way —
`setenv("TZ","UTC0")`, `mktime`, `setenv` back — and newlib reallocates the
environment entry whenever the replacement value is longer, leaking the old
buffer. The main loop converts once a second: 2160 B/minute, measured flat over
fourteen minutes. That is ~130 KB an hour, so the heap emptied in about an hour
and then sat at the floor; at the next Wi-Fi bring-up a ~60 byte
`MALLOC_CAP_INTERNAL` allocation failed inside `phy_track_pll_init`, where IDF's
`ESP_ERROR_CHECK` aborts and reboots the board.

Replaced with `days_from_civil` — pure arithmetic, no libc state, no
allocation. Not by preference: this toolchain has no `timegm` in its headers or
its `libc.a`, and picolibc ships it only under `test/`. Checked against
reference `timegm` before flashing, including the value the self-test pins, a
leap day and the 2038 boundary. Verified after: thirteen consecutive minutes at
+0 bytes.

Every earlier hunt missed it because they all tested the fetch path, which is
clean. The leak was in the per-minute UI tick — the surface `wifi_stress.c`
never touched. The `alloc_watch` guard added earlier in this branch is what made
it findable: it converted the reboot into a stale reading, so the evidence
survived.

**A failed sync no longer bricks the clock.** It used to spin forever on
"Please reset the device" — a flat access point, a slow DHCP lease or one
low-memory moment left a dead-looking board waiting for a button this hardware
does not have. It now carries on and retries, and the retry rides the existing
weather slot: forcing it on its own turned a missed sync into a Wi-Fi attempt
every single minute.

**It no longer states a time it does not have.** This build has no backup cell
on the PCF85063, so the RTC survives a reset but not an unplug, after which the
chip returns a well-formed *wrong* time. Bit 7 of the seconds register is the
oscillator-stop flag that says so, and `Pcf85063_GetTime()` masks it off to read
the seconds — so it needed reading separately. A cold boot with no network shows
`--:--` until a sync lands.

**A failed weather refresh no longer reboots the device.** `ESP_ERROR_CHECK`
aborts, which is defensible at first-boot bring-up and wrong on anything that
runs repeatedly: a failed refresh should cost a stale reading, not an uptime.

**The RTC stores UTC**, with the timezone applied only for display.

**One connect attempt per bring-up.** `WifiSync` was calling `esp_wifi_connect()`
while the `STA_START` handler was already doing so.

**Display timing**: wait for the actual SPI transfer rather than a padded delay;
batch the flush callback's send to once per refresh pass; restore the
post-refresh settling delay, which was the real cause of the vertical roll.

**Layout fixes** found by measuring rather than by eye: top-bar readings sized
for their widest values; the face date sized for the widest date rather than a
lucky one (`Fri 21` fitted, `Wed 24` did not); the restart diagnostic made
actually visible, having been drawn off the bottom of a 300px panel.

### Removed

**Windowed partial refresh.** Added, reverted, restored and reverted again —
the vertical roll it was meant to fix turned out to be the missing settling
delay. The spec records the clean re-test rather than pretending the detour did
not happen.

### Known issues

None outstanding. The `ESP_ERR_NO_MEM` abort inside `phy_track_pll_init` that
this branch carried as unexplained was found and fixed on 2026-09-12 — see
**Fixed: the clock tick leaked 32 bytes a second** below.

### Unverified

The `--:--` path is logically exercised but has not been reproduced on hardware:
raising the oscillator-stop flag needs a real power cycle, and USB keeps the
board powered.

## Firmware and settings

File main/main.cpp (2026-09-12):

#include <stdio.h>
#include <freertos/FreeRTOS.h>
#include <esp_timer.h>
#include <esp_log.h>

#include "display_bsp.h"
#include "lvgl_bsp.h"
#include "user_config.h"
#include "ui.h"
#include "clock_task.h"
#include "clock_time.h"
#include "nav.h"
#include "selftest.h"
#include "wifi_stress.h"
#include "alloc_watch.h"

DisplayPort RlcdPort(12, 11, 5, 40, 41, LCD_WIDTH, LCD_HEIGHT);

static void Lvgl_FlushCallback(lv_display_t *drv, const lv_area_t *area, uint8_t *color_map)
{
    /* A refresh pass can flush several disjoint dirty rects in a row (e.g.
       a screen switch or the hint overlay showing/hiding touches multiple
       widgets at once). RLCD_WaitTransferDone()'s semaphore is only ever
       re-given by the completion callback behind RLCD_Display(), which
       fires just once per pass - so the wait must also happen just once
       per pass, before the pass's first pixel write, not on every flush
       call. Waiting unconditionally here would consume the semaphore's
       token on the first (non-last) flush and never get it back,
       deadlocking the very next flush of the same pass.
       Windowed partial-refresh (sending just the changed sub-rectangle
       instead of the full panel) was implemented and hardware-tested
       2026-08-30, twice: once before Lvgl_Refresh()'s post-send settling
       delay was restored (invalid test, no reliable signal either way -
       see that function's comment), then again after, as a clean test.
       Still no measurable benefit: the ST7305's visible settle cost
       appears roughly fixed per send, not proportional to the addressed
       window's area, so windowing only adds extraction/addressing
       complexity for no win. Always a full-panel send. See git history
       and docs/superpowers/specs/2026-08-30-windowed-partial-refresh-
       design.md for the full investigation. */
    static bool s_batch_in_progress = false;
    if (!s_batch_in_progress)
    {
        RlcdPort.RLCD_WaitTransferDone();
        s_batch_in_progress = true;
    }

    uint16_t *buffer = (uint16_t *)color_map;
    for (int y = area->y1; y <= area->y2; y++)
    {
        for (int x = area->x1; x <= area->x2; x++)
        {
            uint8_t color = (*buffer < 0x7fff) ? ColorBlack : ColorWhite;
            RlcdPort.RLCD_SetPixel(x, y, color);
            buffer++;
        }
    }
    /* Only the last flush of a refresh pass needs to trigger the actual
       transfer: sending after every dirty rect produced N redundant sends
       in a row (see the history of this function for the batching fix
       this superseded). */
    if (lv_display_flush_is_last(drv))
    {
        RlcdPort.RLCD_Display();
        s_batch_in_progress = false;
    }
    lv_disp_flush_ready(drv);
}

extern "C" void app_main(void)
{
    /* First, so the allocation-failure hook is armed before anything large is
       allocated, and so the previous run's record is rescued out of RTC memory
       before anything can overwrite it. */
    AllocWatch_Init();

    /* main.cpp orchestrates every *_RunTests() suite directly: it is the
       one place already required by everything, which keeps components
       under test depending on selftest rather than the reverse. See the
       comment on Selftest_End() in selftest.h. */
    Selftest_Begin();
    ClockTime_RunTests();
    Nav_RunTests();
    Selftest_End();

    /* Compiled out unless CONFIG_CLOCK_WIFI_STRESS is set. Runs here, in
       the same place as the other suites, because it needs the whole
       system up and must finish before ClockTask_Start() begins its own
       Wi-Fi work. */
    WifiStress_Run();

    RlcdPort.RLCD_Init();
    /* RLCD_Init() only memsets DispBuffer to white (RLCD_ColorClear) and
       never sends anything, so without an explicit send here the panel's
       actual contents are whatever they were left in before this boot
       (stale, from before flashing, or garbage) until the first LVGL
       flush happens to cover it. Make that explicit instead of relying on
       LVGL's first screen-load happening to invalidate the whole display.
       Order matters: WaitTransferDone() first consumes the semaphore's
       initial free token (given in the constructor, nothing in flight
       yet), so RLCD_Display() right after it queues a send behind a
       semaphore that's now correctly "taken" - the next WaitTransferDone()
       call (the first real LVGL flush) will genuinely block until this
       transfer completes rather than falling through on a token nobody
       consumed yet. */
    RlcdPort.RLCD_WaitTransferDone();
    RlcdPort.RLCD_Display();
    gpio_sleep_sel_dis(GPIO_NUM_12);
    gpio_sleep_sel_dis(GPIO_NUM_11);
    gpio_sleep_sel_dis(GPIO_NUM_5);
    gpio_sleep_sel_dis(GPIO_NUM_40);
    gpio_sleep_sel_dis(GPIO_NUM_41);
    Lvgl_PortInit(400, 300, Lvgl_FlushCallback);

    if (Lvgl_lock(-1))
    {
        ui_init();
        loadScreen(SCREEN_ID_INIT);
        Lvgl_Refresh();
        Lvgl_unlock();
    }

    ClockTask_Start();
}

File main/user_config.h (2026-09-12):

#ifndef USER_CONFIG_H
#define USER_CONFIG_H

#define LCD_WIDTH      400
#define LCD_HEIGHT     300

#define RLCD_DC_PIN    GPIO_NUM_5
#define RLCD_CS_PIN    GPIO_NUM_40
#define RLCD_SCK_PIN   GPIO_NUM_11
#define RLCD_MOSI_PIN  GPIO_NUM_12
#define RLCD_RST_PIN   GPIO_NUM_41
#define RLCD_TE_PIN    GPIO_NUM_6

#define ESP32_I2C_SDA_PIN   GPIO_NUM_13
#define ESP32_I2C_SCL_PIN   GPIO_NUM_14

#define BTN_OK_PIN          GPIO_NUM_0    /* BOOT  */
#define BTN_SELECT_PIN      GPIO_NUM_18   /* KEY   */

#endif

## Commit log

2026-09-12 Rework calendar screen: aligned grid, top bar, weather row
    The calendar screen had several defects rooted in it being drawn as one
    space-padded text block on a 1-bit panel.
    Grid:
    - Replace the single space-padded label with one fixed-width centred label
    per weekday column. Montserrat is proportional (digit 1 is 5 px, digit 4
    is 9 px), so columns could never line up; now they align by construction
    and the "Mo..Su" header is line 0 of its own column.
    - Row pitch now comes from text_line_space. The old code set pad_row, which
    labels ignore, so the assumed 22 px pitch was really 16 px.
    - Size and place the today highlight from the same column/row constants, so
    it always lands exactly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
    [clock_task.c]
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2026-09-12 test: add on-device self-test harness
    No host compiler is available, so assertions run at boot and report over
    serial. Deliberately not Unity: RUN_TEST needs setUp/tearDown whose
    provision varies by IDF configuration.
    Also fixes transitive dependency exposure in main, port_bsp and clock
    CMakeLists that became visible when main gained explicit PRIV_REQUIRES.
    [main.cpp]
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2026-09-12 fix: wire clock_time_test.c into the build; it was dead code
    clock_time_test.c existed and defined ClockTime_RunTests(), matching the
    plan, but was never added to clock's SRCS and never called from anywhere.
    selftest.c's tests were a hand-duplicated copy of the same logic instead of
    calling the shipped ClockTime_SetTimezone/UtcToEpoch/UtcToLocal - so the
    self-test suite was passing without ever exercising the code it shipped
    next to.
    An initial fix (selftest.c forward-declaring and calling ClockTime_RunTests
    directly, to sidestep the selftest->clock->main->selftest build cycle)
    compiled but failed to link: ESP-IDF's linker only pulls an archive member
    in to satisfy a symbol reference across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
    [main.cpp]
2026-09-12 fix: store UTC in the RTC, apply timezone only for display
    Pcf85063_SetTime was being handed local time, so DST transitions did not
    take effect until the next scheduled sync (05:00/15:00) - up to 12 hours
    late. It also made a runtime timezone setting impossible, which the
    settings milestone needs.
    WifiSync_SyncTimeOnce now returns UTC via gmtime_r instead of localtime_r.
    clock_task converts to local with ClockTime_UtcToLocal on every RTC read
    and after every NTP sync, and stores UTC in the RTC via Pcf85063_SetTime.
    Verified on-device: displayed time matches wall-clock local time, and
    stayed correct across several reboots.
    [clock_task.c]
2026-09-12 feat: add two-button input layer with long-press detection
    Select on GPIO18, OK on GPIO0. Debounces, classifies short vs long press
    (600ms threshold), blocks until release so one physical push cannot emit
    twice. btn_event_t lives in ui/ rather than input/ so the nav state
    machine (Task 5) can consume it without depending on the GPIO layer.
    Verified on hardware: both pins read 1 at rest and drop to 0 while held,
    confirmed via an on-screen probe rather than serial (this board's native
    USB-Serial/JTAG proved too unreliable to capture from reliably in this
    environment - see the flash notes below).
    Also fixes clock_task.c's existing single-button code to use the renamed
    BTN_OK_PIN in place of t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
    [buttons.c, clock_task.c, user_config.h]
2026-09-12 feat: add navigation state machine
    Pure C, no LVGL or ESP-IDF dependency - so it's covered by both an
    exhaustive host-side invariant check (tools/verify_nav.py, 92 reachable
    states) and an on-device assertion suite, agreeing with each other.
    Nav_RunTests is called from main.cpp alongside ClockTime_RunTests,
    following the pattern fixed in f45dcbe: components under test add selftest
    to their own PRIV_REQUIRES, never the reverse. ui only requires lvgl, so
    ui -> selftest is not cyclic the way clock -> selftest would have been.
    Also adds Selftest_GetCounts(), a small permanent addition used to verify
    this on-device: the selftest summary prints in well under a second of
    boot, tighter than serial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
    [main.cpp]
2026-09-12 refactor: move the top bar to lv_layer_top
    lv_layer_top floats above whichever screen is loaded (confirmed on-device:
    a probe label stayed visible through create_screens, loadScreen(INIT),
    and a real screen switch to the calendar), so one widget set now serves
    every screen. Removes the duplicate bar added in ccffbf5 - 11 widgets
    deleted (7 from main, 4 from the calendar's own copy), 7 added once in
    Overlay_Create.
    Verified on hardware: top bar correct on main, and the same bar - not a
    second copy - stays correct after switching to the calendar screen.
    Also fixes a real build-system bug hit while doing this: components/ui's
    CMakeLists.txt used file(GLOB_RECURSE ui_srcs "*.c") with no
    CONFIG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
    [clock_task.c]
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2026-09-12 feat: drive screens from the navigation state machine
    Select cycles screens, OK enters focus mode, long OK reaches settings.
    Replaces the single-button screen toggle.
    Hint overlay redesigned to a single line, Key-then-Boot badges (inverted
    boxes), matching the sibling project's silkscreen-name convention. Hint
    wording is now checked against nav.c's actual transition table: Focus's
    Boot-hold reaching Settings, Detail's Key-hold reaching Back, and
    Settings's Key-hold being the real Exit action (previously wrongly
    attributed to Boot's hold, which is a no-op while already in Settings)
    are all documented now.
    Also fixes two real bugs found during hardware verification:
    - Button presses were si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
    [buttons.c, clock_task.c, display_bsp.cpp]
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2026-09-12 fix: wait for the actual SPI transfer instead of a padded delay
    Lvgl_FlushCallback now waits on a real on_color_trans_done completion
    signal before writing this frame's pixels, replacing a blind 50ms
    vTaskDelay that was informally protecting DispBuffer (single-buffered,
    not safe to mutate while a previous transfer is still in flight) against
    a race it never actually proved safe against.
    [display_bsp.cpp, main.cpp]
2026-09-12 fix: batch the flush callback's SPI send to once per refresh pass
    Task 1's transfer-done wait was correct but unconditional per flush
    call, while RLCD_Display() - the only thing that re-gives the wait
    semaphore - now needs to run just once per refresh pass instead of
    once per dirty rect. Waiting on every flush deadlocked the first
    compound UI change after boot: the wait ate the semaphore's token
    on a non-last flush with no send to return it, and the batch's next
    flush blocked forever (observed as the device hanging on "Time
    synced.").
    Fix: track whether a batch is in progress with a static flag, wait
    only on the first flush of a pass, and send only on the last flush
    (per lv_display_flush_is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
    [main.cpp]
2026-09-12 docs: record that the HPM/LPM frame-rate register isn't the roll's cause
    Tried staying in HPM (~25.5Hz) instead of dropping to LPM (1Hz) after
    init, on the theory that LPM's slow frame rate explained the visible
    "roll" on large-area screen updates. Hardware-measured on the real
    device: no difference - same ~50px/sec roll in both modes. This rules
    out the frame-rate register as the cause and points at the panel's own
    liquid-crystal optical settling time instead, which isn't addressable
    via this register. Reverted to LPM (no reason to pay its power cost
    for a mode that gave no visible benefit), keeping only the comment so
    this dead end doesn't get retried.
    [display_bsp.cpp]
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2026-09-12 fix: complete clamping, drop the fallback threshold, boot-sync send
    Final whole-branch review + a design change requested after it:
    - RLCD_ComputeWindow(): fully clamp each coordinate independently (not
    just the outer bound of each pair) and un-reverse a swapped rect -
    closes a path to a negative RlcdWindow.len reaching the DMA layer's
    size_t parameter as a huge unsigned value. Unreachable via LVGL today,
    but the function's own doc comment already claimed this guarantee.
    - RLCD_DisplayAuto(): drop the 80%-height fallback threshold entirely -
    it wasn't actually shrinking anything for the case it was meant to
    help (a Main<->Cal+Clock screen switch), since LVGL's own
    lv_screen_lo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
    [display_bsp.cpp, main.cpp]
2026-09-12 docs: drop the stale 80%-threshold reference in Lvgl_FlushCallback
    Caught by the fix wave's own re-review: this comment, just outside
    the diff that removed the threshold, still described the dropped
    behavior. Text-only correction, no logic change.
    [main.cpp]
2026-09-12 fix: gate windowed refresh to the Main screen's clock-digit column only
    Hardware testing found the panel's visible settle artifact does not
    track a window's pixel area - it tracks how much of the window's own
    content changes. The hint overlay's window is smaller than a clock
    digit's (3 CASET units vs ~12) but its border+background flip nearly
    all at once, reading as worse than a digit swap on white background
    despite the smaller window. DisplayPort only sees a rectangle, not
    pixel content, so window size can't be the gate.
    What's confirmed acceptable on hardware is windowing specifically for
    the Main screen's digital clock column (clock_hh1/hh2/mm1/mm2 + the
    colon). Hardcode that one region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
    [main.cpp]
2026-09-12 revert: drop windowed partial-refresh, back to full-panel send
    Three rounds of hardware testing (2026-08-30, all after the clock-digit-
    area-only gate from the previous commit) found no configuration of
    windowed partial-refresh actually helps: the ST7305's visible settle
    artifact tracks how much of a window's own content changes, not the
    window's pixel area, so no geometry-based policy (an 80% threshold, no
    threshold, a hardcoded clock-digit allow-list) reliably separated an
    acceptable case from an unacceptable one. Even the one case confirmed
    'acceptable' (the clock digit column) showed a buggy rollover on
    hardware once isolated.
    Removes RLCD_ComputeWindow(), RLCD_DisplayWindow(), RLCD_Dis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
    [display_bsp.cpp, main.cpp]
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2026-09-12 revert: restore windowed partial-refresh on top of the settling-delay fix
    Every previous windowing test (always-window, threshold-gated, clock-
    digit-allow-list) ran while the real settling delay was still missing
    (see 04e0c4e) - none of them were a valid test of whether windowing
    itself helps, only of whether it could compensate for broken timing.
    It couldn't, so windowing got reverted (4190ff3) for the wrong reason.
    Restores the always-window implementation from commit 44041b9
    (RLCD_ComputeWindow/RLCD_DisplayWindow/RLCD_DisplayAuto, WindowBuffer,
    display_bsp_test.cpp, the union-rect tracking in Lvgl_FlushCallback),
    verbatim except for comments updated to reflect the corrected history.
    Thi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
    [display_bsp.cpp, main.cpp]
2026-09-12 revert: drop windowed partial-refresh again, this time confirmed
    A hardware A/B test on top of the restored settling delay (04e0c4e)
    showed no benefit from windowing either: the hint overlay's window and
    a full-panel screen switch settle at about the same visible speed.
    Unlike the first revert (4190ff3, wrong conclusion - that test ran
    without the settling delay, an invalid comparison), this is windowing's
    first and only clean test. The panel's settle cost appears roughly
    fixed per send, not proportional to the addressed window's area, so
    windowing adds extraction/addressing complexity for no measurable win.
    Comments updated in main.cpp, lvgl_bsp.cpp, and display_bsp.cpp to
    record both atte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
    [display_bsp.cpp, main.cpp]
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2026-09-12 refactor: flatten firmware/ into repo root
    Move the ESP-IDF project (CMakeLists.txt, main/, components/, sdkconfig,
    sdkconfig.defaults, partitions.csv, dependencies.lock, .clangd) up from
    firmware/ to the repo root so the ESP-IDF VS Code extension picks up the
    project when the repo is opened at its root. firmware/ is removed.
    - Merge firmware/.gitignore into the root .gitignore.
    - Fix live path references in README.md and tools/verify_nav.py.
    - Historical docs under docs/superpowers/ keep their firmware/ paths as
    point-in-time records.
    [partitions.csv]
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2026-09-12 fix: keep the clock tick on a real 1s cadence and de-speckle the minor ticks
    The per-second Cal+Clock dial redraw added ~150-200ms of render+SPI work
    per loop iteration; a fixed 1s light-sleep on top of that made the RTC
    read skip a second in a regular beat (~1 in 6). Sleep is now compensated
    by the previous iteration's measured work time.
    The 60 minor tick marks were 2px radial lines that broke into speckle at
    diagonal angles under the 1-bit threshold. Replaced with 3x3 dithered-grey
    dots near the rim (Dither_Threshold from Task 2), which are axis-aligned
    and render identically at every clock position.
    [clock_task.c]
2026-09-12 feat: per-cell calendar grid with working month browsing
    Replaces the one-multi-line-label-per-column grid with one label per
    cell so leading/trailing days can render in a smaller font than the
    current month - a single lv_label cannot mix fonts. Adds real
    focus/action for the < > month arrows: two new Cal+Clock focusables,
    reusing the same act-then-bounce-back-to-FOCUS pattern NAV_SETTINGS
    already relies on, since nav.c has no notion of a focused element just
    performing an action. No nav.c change.
    Supersedes the parent spec's per-day focus and day-detail overlay -
    see the 2026-08-29 spec amendment for why.
    [clock_task.c]
2026-09-12 fix: guard the displayed-month state against an RTC read failure on entry
    apply_nav_visuals() only seeds s_cal_disp_year/month when its RTC read
    succeeds; a transient failure at first Cal+Clock entry left them at -1 and
    every later update_calendar_display() call rendered MONTHS[-1] until the
    screen was re-entered. Seed lazily from the loop's validated `now` at the
    point of use. Also refresh the now-stale calendar-layout comment.
    [clock_task.c]
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2026-09-12 feat: five-slot top bar, date moves onto the clock face
    The top bar becomes its final layout: indoor reading + trend arrow,
    humidity + trend arrow, outdoor forecast icon + temperature, a sync
    glyph, and the battery box. The trend arrows and the sync glyph are
    created as sized placeholders - nothing writes to them yet - so the
    slot budget is fixed now and the row cannot reflow when the data
    behind them lands.
    Slot budget, each width taken from montserrat_20's real adv_w table
    for that slot's widest possible value:
    1 indoor x6 w80 "-88.8" + arrow
    2 humidity x106 w71 "100%" + arrow
    3 weather x197 w68 24px icon + "-25"
    4 sync x285 w25 LV_SYMBOL_WIFI measures 2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
    [clock_task.c]
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2026-09-12 fix: size the face date for the widest date, not a lucky one
    "Fri 21" was a flattering sample. The real worst case is "We 24" / "Wed 24",
    and measured against the montserrat adv_w tables the previous setup did not
    fit it:
    3-letter @16pt 63px
    2-letter @16pt 52px
    3-letter @14pt 55px
    2-letter @14pt 45px <- the only combination that fits
    The channel between the hour and minute digits is 49px wide (the widest
    saira_condensed_bold200 glyph, '8', overflows its own 90px column and leaves
    ink free only from about x172 to x221), so anything above ~46px would have
    collided with a neighbouring digit on the wide dates.
    So the face date drops to montserrat_14 and the two-letter weekday th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
    [clock_task.c]
2026-09-12 feat: stack the face date, weekday over day number
    The colon column is far tighter horizontally than vertically, so setting the
    date on one line was solving the wrong problem. On one line the widest date
    ("We 24") is 45px at montserrat_14 against a 49px ink-free channel; stacked,
    the widest line is just "24", and the font can go back up to 16pt with room
    to spare.
    Two montserrat_16 lines are 36px (line_space defaults to 0), leaving 11px
    above and below inside the 58px gap between the colon's dots. The block is
    centred on y114 - the optical centre found on hardware, four pixels above
    the y118 the arithmetic gives - so it starts at y96, and keeps the x198
    centre axis the one-line version used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
    [clock_task.c]
2026-09-12 feat: fetch current conditions, and make the battery box a fuel gauge
    The top bar's outdoor slot was showing today's forecast HIGH, because
    WeatherDay only ever carried temp_max/temp_min/weathercode. Open-Meteo's
    current_weather block now comes back in the same request and lands in a new
    WeatherNow struct, which carries its own validity flag: a response missing
    that block is still a usable forecast, so it never fails the fetch, and the
    slot falls back to today's high rather than going blank.
    The battery reading becomes a Kindle-style fuel gauge - the existing hollow
    box, with a solid black fill 50px wide at full charge inside a 2px inset. It
    is solid rather than dithered on purpose: a stipp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
    [battery.c, clock_task.c]
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2026-09-12 feat: refresh weather every 30 minutes, independently of the time sync
    A "current" temperature that is up to ten hours old is not a current
    temperature. The RTC and the weather were sharing one twice-daily sync
    because the RTC set the cadence; they are now separate concerns on separate
    cycles, sharing a WiFi bring-up whenever they coincide.
    The RTC is still disciplined only at 05:00 and 15:00 - it drifts slowly and
    there is no reason to spend WiFi on it more often. SNTP still runs on every
    weather refresh because that is what WifiSync_SyncTimeOnce does, but the RTC
    is only written on a time_due tick, so a weather refresh cannot jump the
    clock.
    The slot counter advances even when the fetch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
    [clock_task.c]
2026-09-12 feat: fill the sync slot with a data-stale warning
    The useful signal on this device is not link state - WiFi is down almost all
    the time by design, so a live "connected" icon would read disconnected
    almost always and mean nothing. What matters is whether the reading on
    screen is still worth believing.
    So the slot shows nothing while the last successful fetch is recent, and
    LV_SYMBOL_WARNING once three refresh cycles have passed without one. One
    failed fetch is a blip; three in a row is an outage worth surfacing. An
    always-present icon would be noise - the quiet default is the point.
    Staleness is measured with esp_timer, which keeps running across light
    sleep, and starts negative so that a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
    [clock_task.c]
2026-09-12 diag: show the last reset reason, and follow the weather cycle in the sync label
    Investigating a reboot that happens on the weather refresh. Two candidates
    fit the symptom equally well - a panic from the ESP_ERROR_CHECK calls around
    esp_wifi_start(), which abort on any non-OK return every time WiFi is
    re-started after boot, and a brownout from WiFi TX current peaks. They need
    completely different fixes, and esp_reset_reason() separates them
    immediately.
    It goes on the panel, not just into the log: the serial link to this board
    is unreliable, and the event under investigation happens hours apart, so a
    log nobody is attached to would not be read.
    Also fixes an inconsistency introduced when w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
    [clock_task.c]
2026-09-12 fix: do not reboot the device when a WiFi refresh fails
    esp_wifi_set_mode/set_config/start were wrapped in ESP_ERROR_CHECK, which
    aborts - and therefore reboots - on any non-OK return. That is defensible
    for the first call at boot, where a failure means the device is unusable
    anyway. It is not defensible on a refresh: this function now runs every 30
    minutes, and by then a transient error is something to report and retry, not
    to die on. A failed refresh should cost a stale reading, not an uptime.
    ESP_ERR_WIFI_NOT_STOPPED and ESP_ERR_WIFI_CONN from esp_wifi_start are
    treated as success - they mean a previous run tore down incompletely and the
    radio is usable as it stands.
    The status slot now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
    [clock_task.c]
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2026-09-12 feat: stay awake while a USB host is attached
    Light sleep suspends the USB Serial/JTAG peripheral and this project's
    console has no UART fallback, so sleeping through every second is what makes
    COM8 vanish while the application runs. The console is unreadable, and
    flashing has to race a window that is mostly not there - a 40-attempt retry
    loop failed every time, and the one that eventually succeeded took 206.
    With a host actually attached none of that is worth saving: the board is on
    USB power. So the loop now waits with vTaskDelay instead of sleeping, and the
    port stays up.
    usb_serial_jtag_is_connected() tracks SOF packets rather than bus voltage, so
    a charger or power bank reads as not-c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
    [clock_task.c]
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2026-09-12 fix: make the restart diagnostic actually visible, and name all its causes
    Two defects in the diagnostic itself, both of which made it report nothing
    useful about the reboot it exists to explain.
    **The second line was drawn off the panel.** objects.sync sits at y285 on a
    300px screen and montserrat_12's line_height is 15, so "Last restart: ..."
    landed at y300..315 - rendered and invisible. It reads as a missing feature,
    which is exactly how it was reported. Everything is now one abbreviated line:
    ~276px inside the 400px width, where the old first line alone was 313px and
    the naive one-line combination would have been 447px.
    **Five reset reasons had no case.** IDF 5.5 defines ESP_RST_USB, J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
    [clock_task.c]
2026-09-12 feat: make the status line live, with minutes, so a reboot is legible
    The line only redrew on a sync, so its uptime advanced twice an hour and
    could not distinguish "just rebooted" from "rebooted a while ago" - which is
    the one distinction it exists to support. It now redraws every minute from a
    stored last-sync time, and carries minutes as well as days and hours.
    This is what makes the decisive experiment possible without a host: run the
    board on battery past a couple of refresh boundaries, then read the panel. A
    low uptime means it restarted on its own; a high one means it did not, and
    the reboots were the host touching the serial port. That question cannot be
    answered over USB, because o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
    [clock_task.c]
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2026-09-12 feat: print the raw reset code, since IDF collapses the two USB causes
    esp_reset_reason() cannot tell the two USB reset paths apart on ESP32-S3:
    esp32s3/reset_reason.c maps RESET_REASON_CORE_USB_UART (0x15) and
    RESET_REASON_CORE_USB_JTAG (0x16) to the same ESP_RST_USB. That distinction
    is the useful one here - 0x15 is the CDC side, so esptool or a serial monitor
    opening the port, and 0x16 is the JTAG side, so a debugger attaching. Both
    show as "USB-host" and there is no way to tell which tool did it.
    The status line and the boot log now carry esp_rom_get_reset_reason(0)
    alongside the mapped name, as "USB-host/15".
    Also notes in the switch that ESP_RST_JTAG is unreachable on this chip - onl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
    [clock_task.c]
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
